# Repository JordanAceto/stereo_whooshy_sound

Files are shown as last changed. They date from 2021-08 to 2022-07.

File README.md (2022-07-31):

# Stereo Whooshy Sound

## This pedal accommodates various VCF plug-in boards and contains rich modulation features.
- The interface is loosely modeled after the Mu-Tron Bi-Phase with some additions.
- Flexible signal path configurations are possible, including true stereo, dual-mono, and series setups.

## [SCHEMATIC](https://github.com/JordanAceto/stereo_whooshy_sound/blob/master/hardware/main_pcb/construction_docs/stereo_whooshy_sound_schematic.pdf)

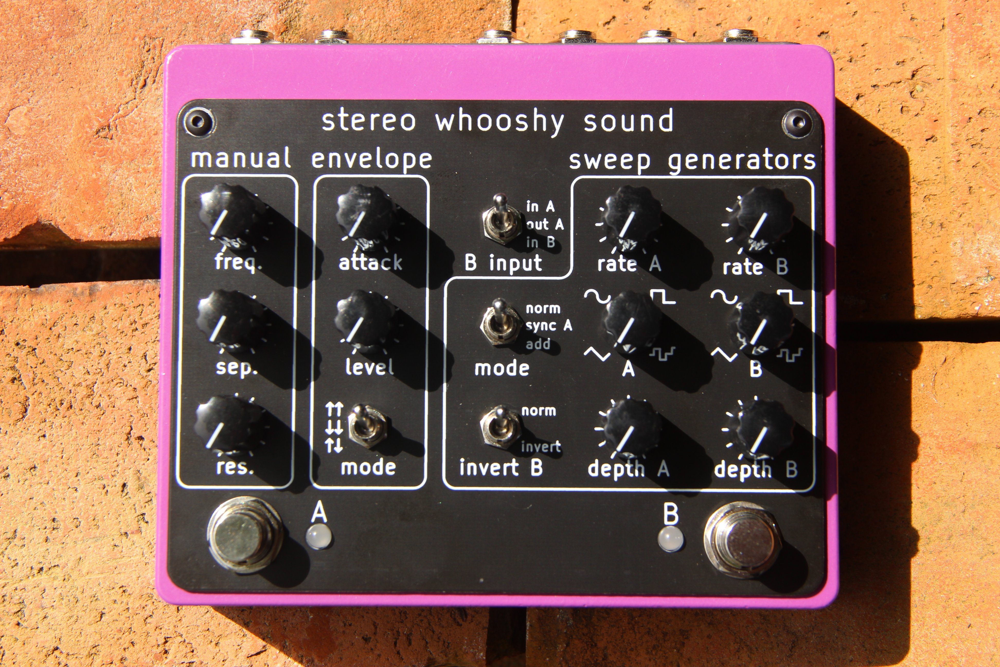
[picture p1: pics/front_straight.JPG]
stereo whooshy sound pedal


### Features:
- Guitar pedal style stomp box.
- Can accept a wide variety of [filter plug-in boards](https://github.com/JordanAceto/VCF_plug_in_boards).
- Manual frequency and resonance controls.
- Dual digitally generated LFO with morphing waveshaper, smoothly crossfades from triangle to sine to square to sample & hold.
- Analog envelope follower for when you want to quack and bwow instead of whoosh.
- CV/expression pedal inputs for each filter.

## Status of the project:

Task | Status |
---------|--------------|
Schematic capture | &#9745;
PCB layout | &#9745;
Test build | &#9745;
Safe to order boards| &#9744;

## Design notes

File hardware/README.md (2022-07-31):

# The hardware for the pedal.

- The [main pcb](https://github.com/JordanAceto/stereo_whooshy_sound/tree/master/hardware/main_pcb) is the heart of the project.

- Once the pedal is built, you need at least two [VCF plug-in boards](https://github.com/JordanAceto/VCF_plug_in_boards) to complete the project.

- Various filter plug-in boards can be swapped in and out to experiment with sounds.

- The front panel and jack panel are simple pcb panels as a cheap way to get an ok looking finished project.

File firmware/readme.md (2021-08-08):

# STM32L031 Low Frequency Oscillator

### Based on the LFO used in the [variable slope filter/phaser](http://jhaible.com/legacy/varislope_filter_phaser/varislope_filter_phaser.html) project by the great Jurgen Haible.

---

### Features:

- Three analog control inputs, all ranging from 0v to +3.3v:
    - Frequency: sets the frequency of the LFO, ranges from quite slow to a few tens of Hertz.
    - Wave shape: smoothly crossfades between triangle, sine, square, and sample & hold waveforms.
    - Level: a simple output level control.

- One crossfaded analog output, in the range 0v to +2v.

---

### Brief overview of the algorithm:
- The three control signals are read by the ADC and stored in a buffer via DMA.
- The frequency control is scaled by using a lookup table as an exponential converter.
- Wave shape and level controls are linear.
- A timer configured as a periodic stopwatch sets the sample rate for the LFO.
- The LFO uses a simple form of [direct digital synthesis](https://www.digikey.com/en/articles/the-basics-of-direct-digital-synthesizers-ddss) as its core.
- The LFO waveforms are independently generated:
    - The triangle wave is derived directly from the phase accumulator.
    - The sine wave uses a lookup table.
    - The square wave is also a simple transformation of the raw phase accumulator.
    - A random sample & hold signal is generated via a [Linear Feedback Shift Register](http://citeseerx.ist.psu.edu/viewdoc/summary?doi=10.1.1.43.3639) and sampled at twice the base LFO frequency (this makes it "feel right").
- A wave scanner then smoothly crossfades between the above shapes, in the above order. This creates a fun and intuitive transition from smooth, to choppy, to chaotic LFO shapes.
- Since the LFO is very low frequency and only used for modulation purposes, no attempts to mitigate aliasing are attempted.
- The final analog output is created by a cheap 12 bit SPI DAC.
- Lookup tables are generated by a python script located in the `utils` directory.

---

### Prerequisites for building and flashing the project:
- [arm-none-eabi toolchain](https://developer.arm.com/tools-and-software/open-source-software/developer-tools/gnu-toolchain/gnu-rm/downloads)
- [GNU make](https://www.gnu.org/software/make/)
- [st-link utility](https://www.st.com/en/development-tools/stsw-link004.html)
- A physical st-link device. I use an old [Nucleo board](https://www.st.com/en/evaluation-tools/stm32-nucleo-boards.html).
- If you have a different preferred method of flashing STM32 chips (openocd, etc) then feel free to go wild.

### To build the project:
- `$ make`

### To flash an STM32 chip connected to an st-link programmer via the SWD header:
- `$ make write`

---

### Firmware directory organization:
- `third_party` contains the STM32 supplied CMSIS header-only files, assembly startup routine, and linker script.
- `BSP` is a very basic "Board Support Package", this module initializes and modifies the various stm32 peripherals used by the system.
- `lib` contains user library files.
- `src` contains the main application files.
- `utils` contains non-c language utility source files such as a python lookup table generating script.
- `bin` is the destination for output files generated by the build process.

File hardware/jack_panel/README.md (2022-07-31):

# jack panel:

## The jack panel is simply a cheap and cheerful pcb panel, as an alternative to dymo labels or silkscreening

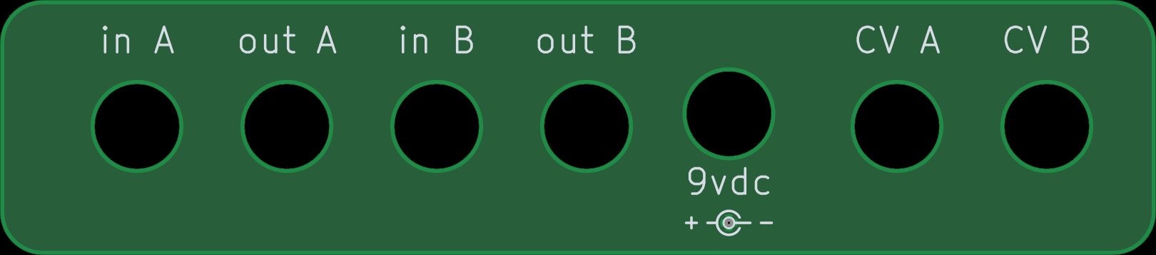
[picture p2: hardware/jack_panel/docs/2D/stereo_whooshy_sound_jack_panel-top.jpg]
jack panel


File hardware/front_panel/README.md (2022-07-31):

# front panel:

## The front panel is simply a cheap and cheerful pcb panel, as an alternative to dymo labels or silkscreening

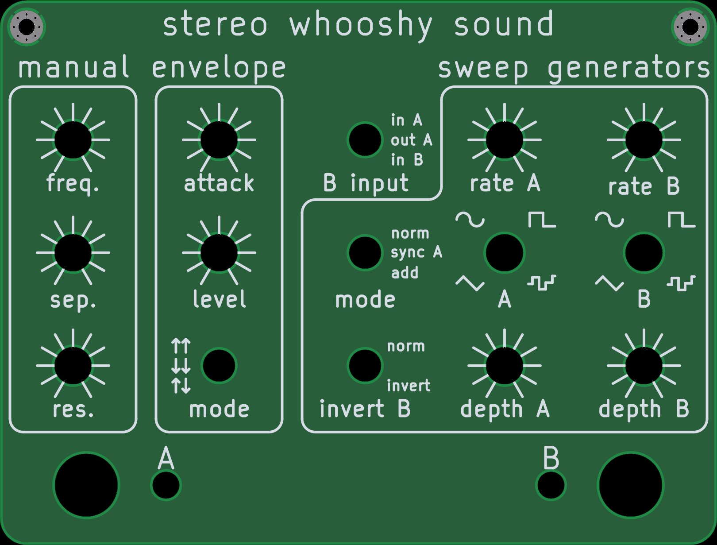
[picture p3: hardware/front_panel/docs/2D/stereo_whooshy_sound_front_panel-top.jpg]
front panel


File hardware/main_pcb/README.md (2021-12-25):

# Main PCB

## The main PCB contains:
- input and output audio buffers
- software generated LFOs
- envelope followers
- two ports which accepts various VCF plug-in boards
- analog bypass switching
- power supply components
- designed to fit in a Hammond 1590XX enclosure

---

## [Schematic](https://github.com/JordanAceto/stereo_whooshy_sound/blob/master/hardware/main_pcb/construction_docs/stereo_whooshy_sound_schematic.pdf)

---

### PCB front view:
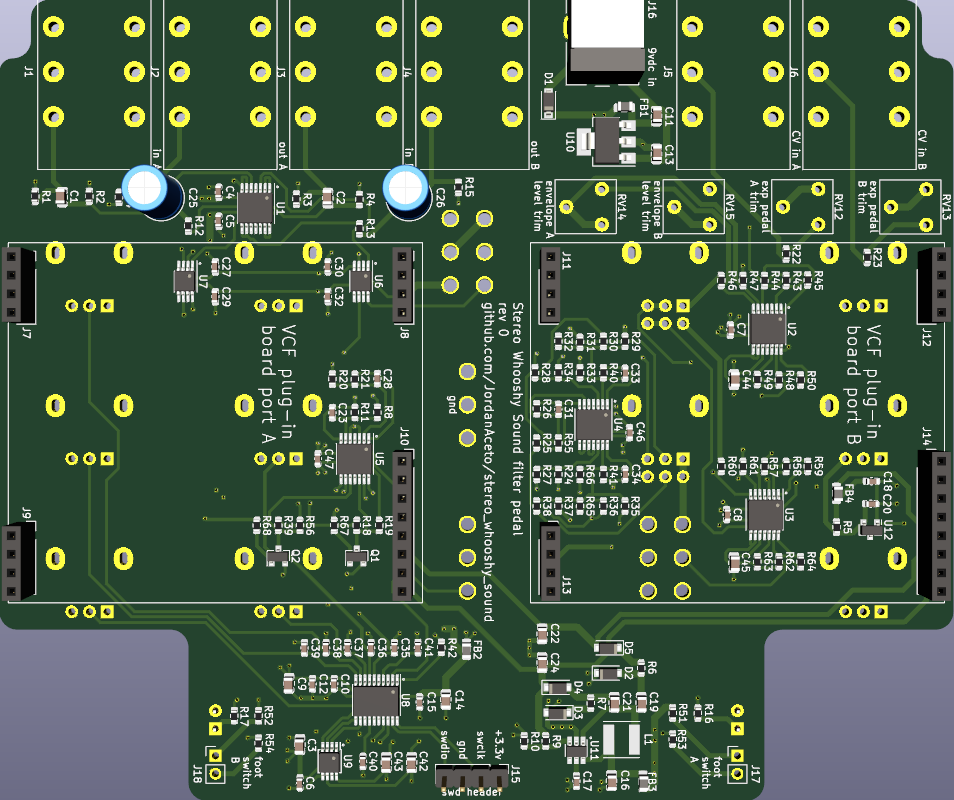
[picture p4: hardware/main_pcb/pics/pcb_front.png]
main PCB front view


---

### PCB rear view:
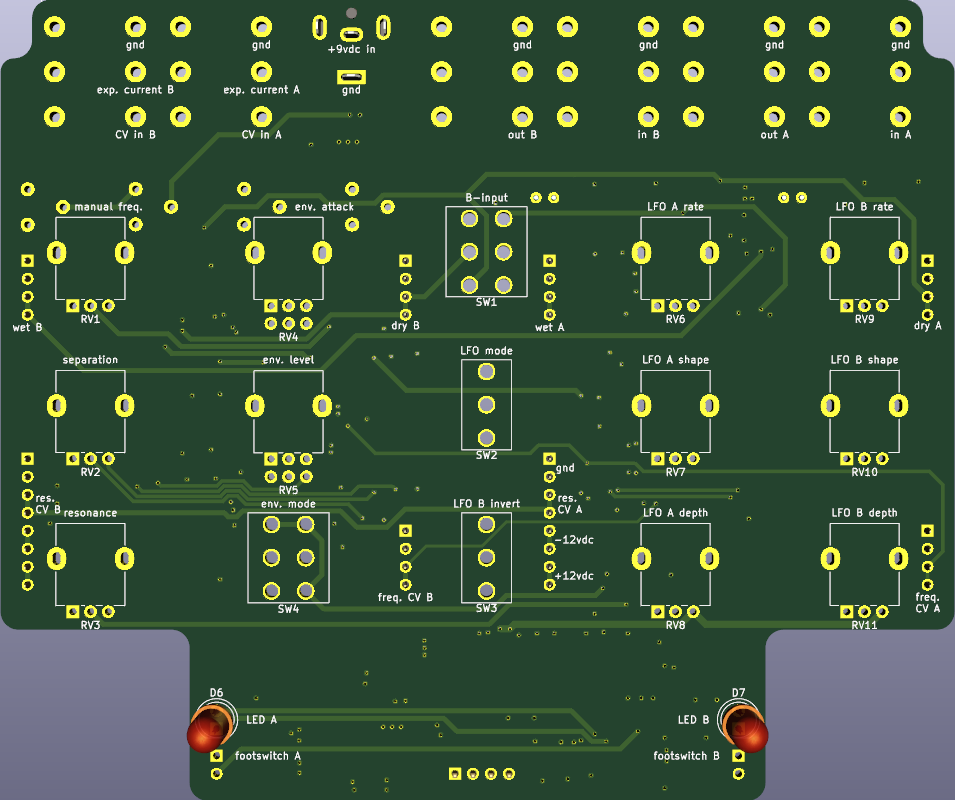
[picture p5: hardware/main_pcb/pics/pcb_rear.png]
main PCB rear view


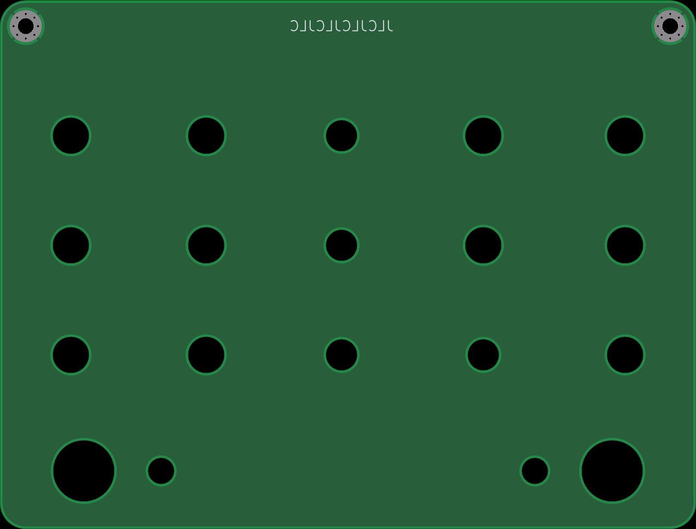
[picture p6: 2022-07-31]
hardware/front_panel/docs/2D/stereo_whooshy_sound_front_panel-bottom.jpg

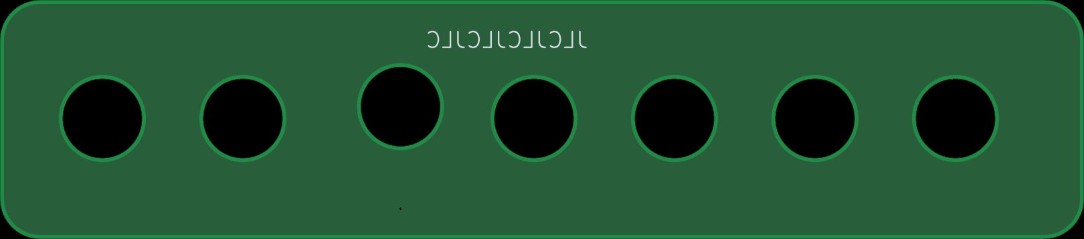
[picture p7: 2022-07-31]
hardware/jack_panel/docs/2D/stereo_whooshy_sound_jack_panel-bottom.jpg

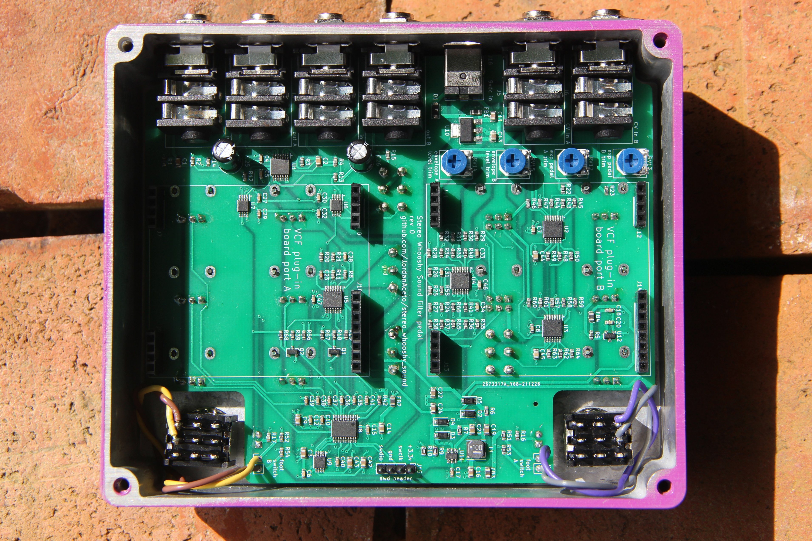
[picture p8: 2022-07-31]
pics/guts_no_plug_in.JPG

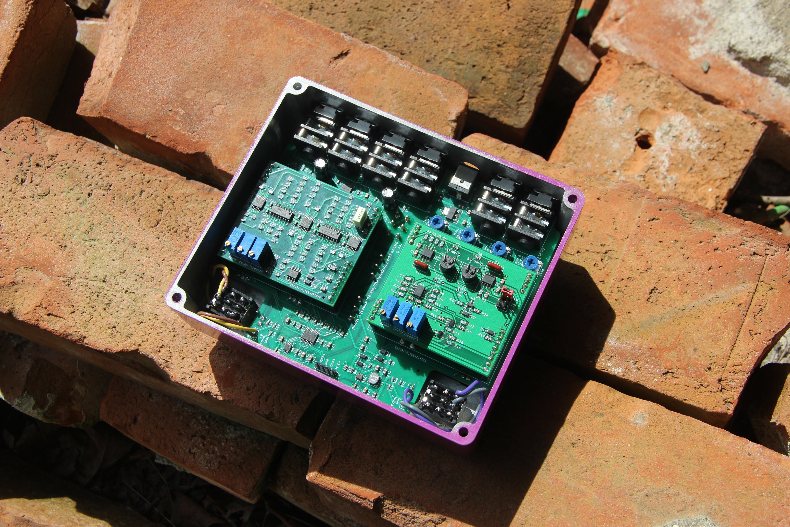
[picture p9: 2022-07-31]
pics/guts_with_plug_in.JPG

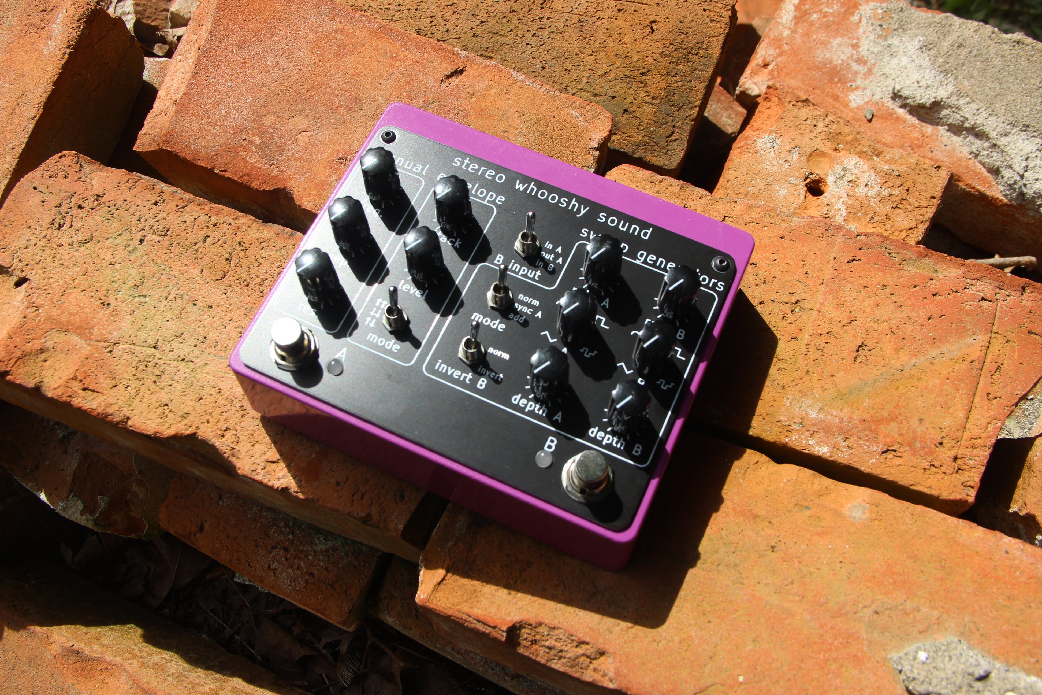
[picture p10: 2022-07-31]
pics/front_angle.JPG

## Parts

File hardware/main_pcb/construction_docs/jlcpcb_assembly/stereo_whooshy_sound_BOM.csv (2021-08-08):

Comment | Designator | Footprint | LCSC Part Number
MMBT3904 | Q1,Q2 | SOT-23-3 | C20526
12k | R19,R56,R27 | 0603 | C22790
120k | R67,R18,R68,R39,R41,R40,R38,R37,R30,R32,R31,R26,R21 | 0603 | C25808
DG469EQ | U7,U6 | MSOP-8_3x3.0x0.65P | C145215
MCP6004 | U5,U4,U3,U2 | TSSOP-14_4.4x5_P0.65P | C50282
TL074 | U1 | TSSOP-14_4.4x5_P0.65P | C96507
300k | R66,R65,R55,R36,R35,R33,R29,R25,R20 | 0603 | C23024
10k | R28,R58,R52,R51,R44,R42,R23,R22,R15,R14 | 0603 | C25804
100k | R24,R64,R63,R62,R50,R49,R48,R34,R8 | 0603 | C25803
1M | R54,R53 | 0603 | C22935
100n | C32,C30,C29,C27,C47,C46,C41,C40,C39,C38,C37,C36,C35,C31,C23,C20,C18,C17,C15,C12,C10,C8,C7,C6,C5,C4 | 0603 | C14663
1k2 | R61,R47,R17,R16,R13,R12 | 0603 | C22765
4k7 | R60,R46 | 0603 | C23162
30k | R59,R45 | 0603 | C22984
20k | R57,R43,R11 | 0603 | C4184
470n | C45,C44 | 0805 | C13967
4n7 | C2,C1 | 0805 | C1744
1R | R7,R6 | 0603 | C22936
2k2 | R5 | 0603 | C4190
2M2 | R4,R3,R2,R1 | 0603 | C22938
100R @ 100MHz | FB4,FB3,FB2,FB1 | L_0805_2012Metric | C1015
B5819W | D1 | D_SOD-123 | C8598
1u | C43,C42,C21,C19,C14 | 0805 | C28323
22n | C34,C33,C28 | 0603 | C21122
4u7 | C24,C22,C16 | 0805 | C1779
10u | C13,C11,C9,C3 | 0805 | C15850

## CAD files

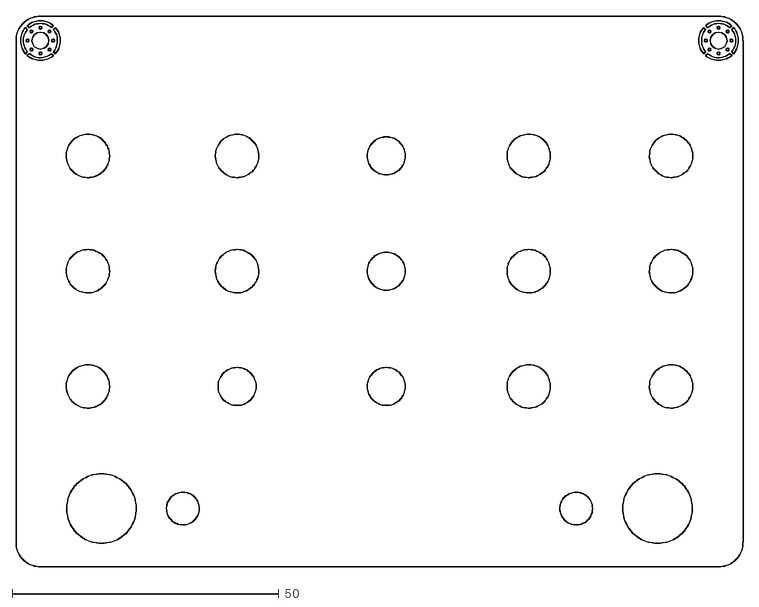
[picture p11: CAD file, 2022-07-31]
hardware/front_panel/docs/CAD/stereo_whooshy_sound_front_panel-B_Cu.dxf
136.1 x 103.1

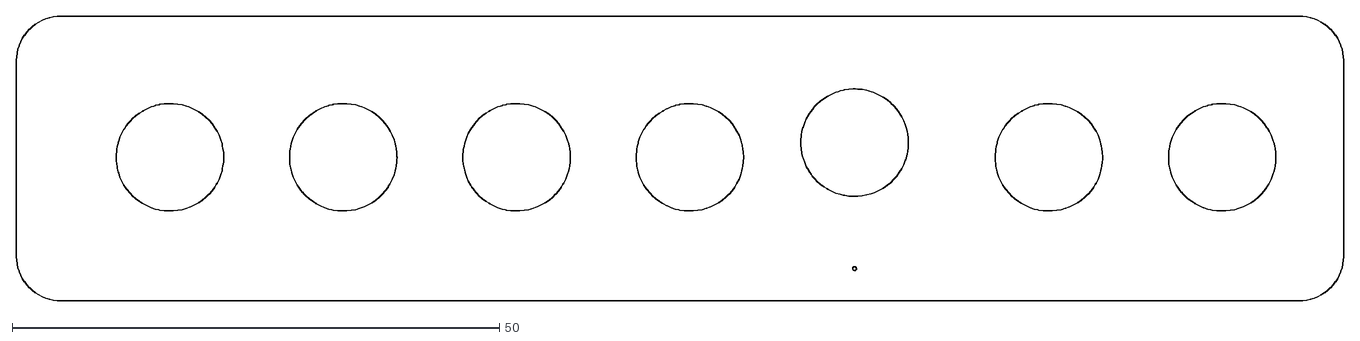
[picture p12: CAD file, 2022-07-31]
hardware/jack_panel/docs/CAD/stereo_whooshy_sound_jack_panel-B_Cu.dxf
136.1 x 29.2

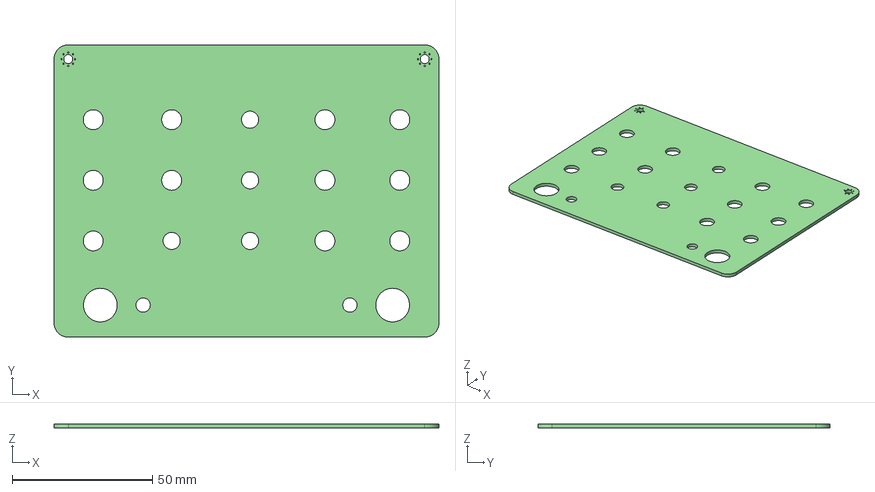
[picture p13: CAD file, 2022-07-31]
hardware/front_panel/docs/CAD/stereo_whooshy_sound_front_panel-3D.step
137.2 x 104.1 x 1.60 mm

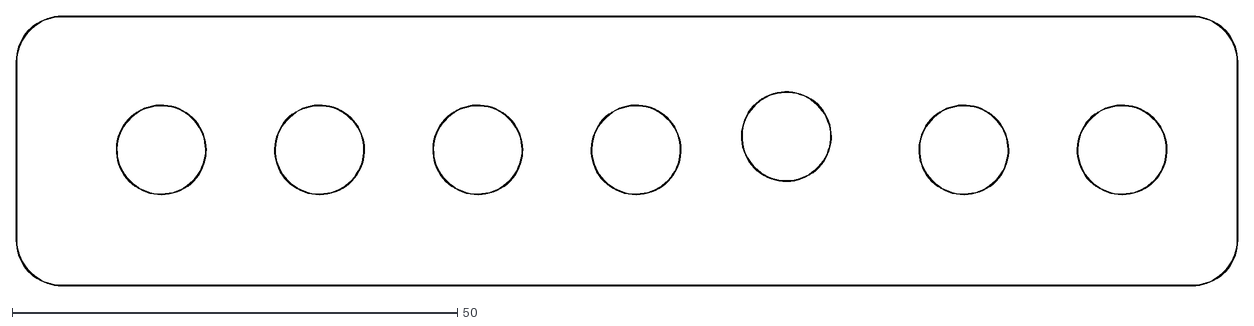
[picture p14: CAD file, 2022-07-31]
hardware/jack_panel/docs/CAD/stereo_whooshy_sound_jack_panel-Edge_Cuts.dxf
137.2 x 30.3

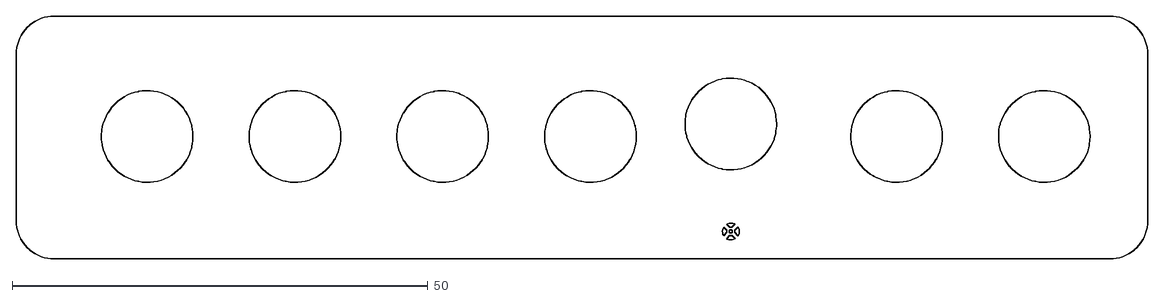
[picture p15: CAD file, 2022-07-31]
hardware/jack_panel/docs/CAD/stereo_whooshy_sound_jack_panel-F_Cu.dxf
136.1 x 29.2

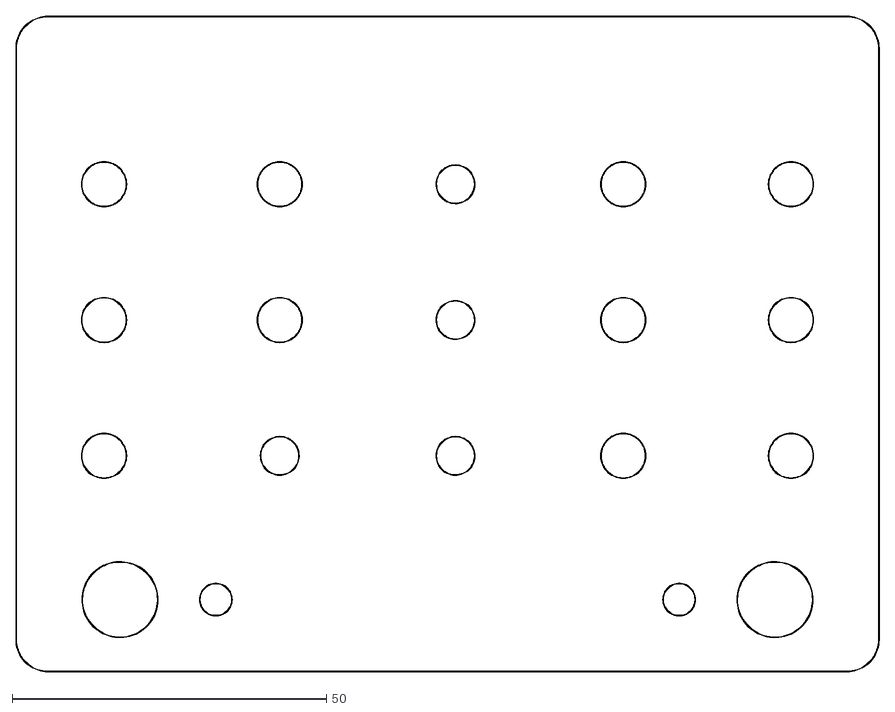
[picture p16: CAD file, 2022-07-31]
hardware/front_panel/docs/CAD/stereo_whooshy_sound_front_panel-Edge_Cuts.dxf
137.2 x 104.2

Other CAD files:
hardware/front_panel/docs/CAD/stereo_whooshy_sound_front_panel-B_Mask.dxf
hardware/front_panel/docs/CAD/stereo_whooshy_sound_front_panel-B_Silkscreen.dxf
hardware/front_panel/docs/CAD/stereo_whooshy_sound_front_panel-F_Mask.dxf
hardware/front_panel/docs/CAD/stereo_whooshy_sound_front_panel-F_Silkscreen.dxf
hardware/jack_panel/docs/CAD/stereo_whooshy_sound_jack_panel-B_Mask.dxf
hardware/jack_panel/docs/CAD/stereo_whooshy_sound_jack_panel-B_Silkscreen.dxf
hardware/jack_panel/docs/CAD/stereo_whooshy_sound_jack_panel-F_Mask.dxf
hardware/jack_panel/docs/CAD/stereo_whooshy_sound_jack_panel-F_Silkscreen.dxf

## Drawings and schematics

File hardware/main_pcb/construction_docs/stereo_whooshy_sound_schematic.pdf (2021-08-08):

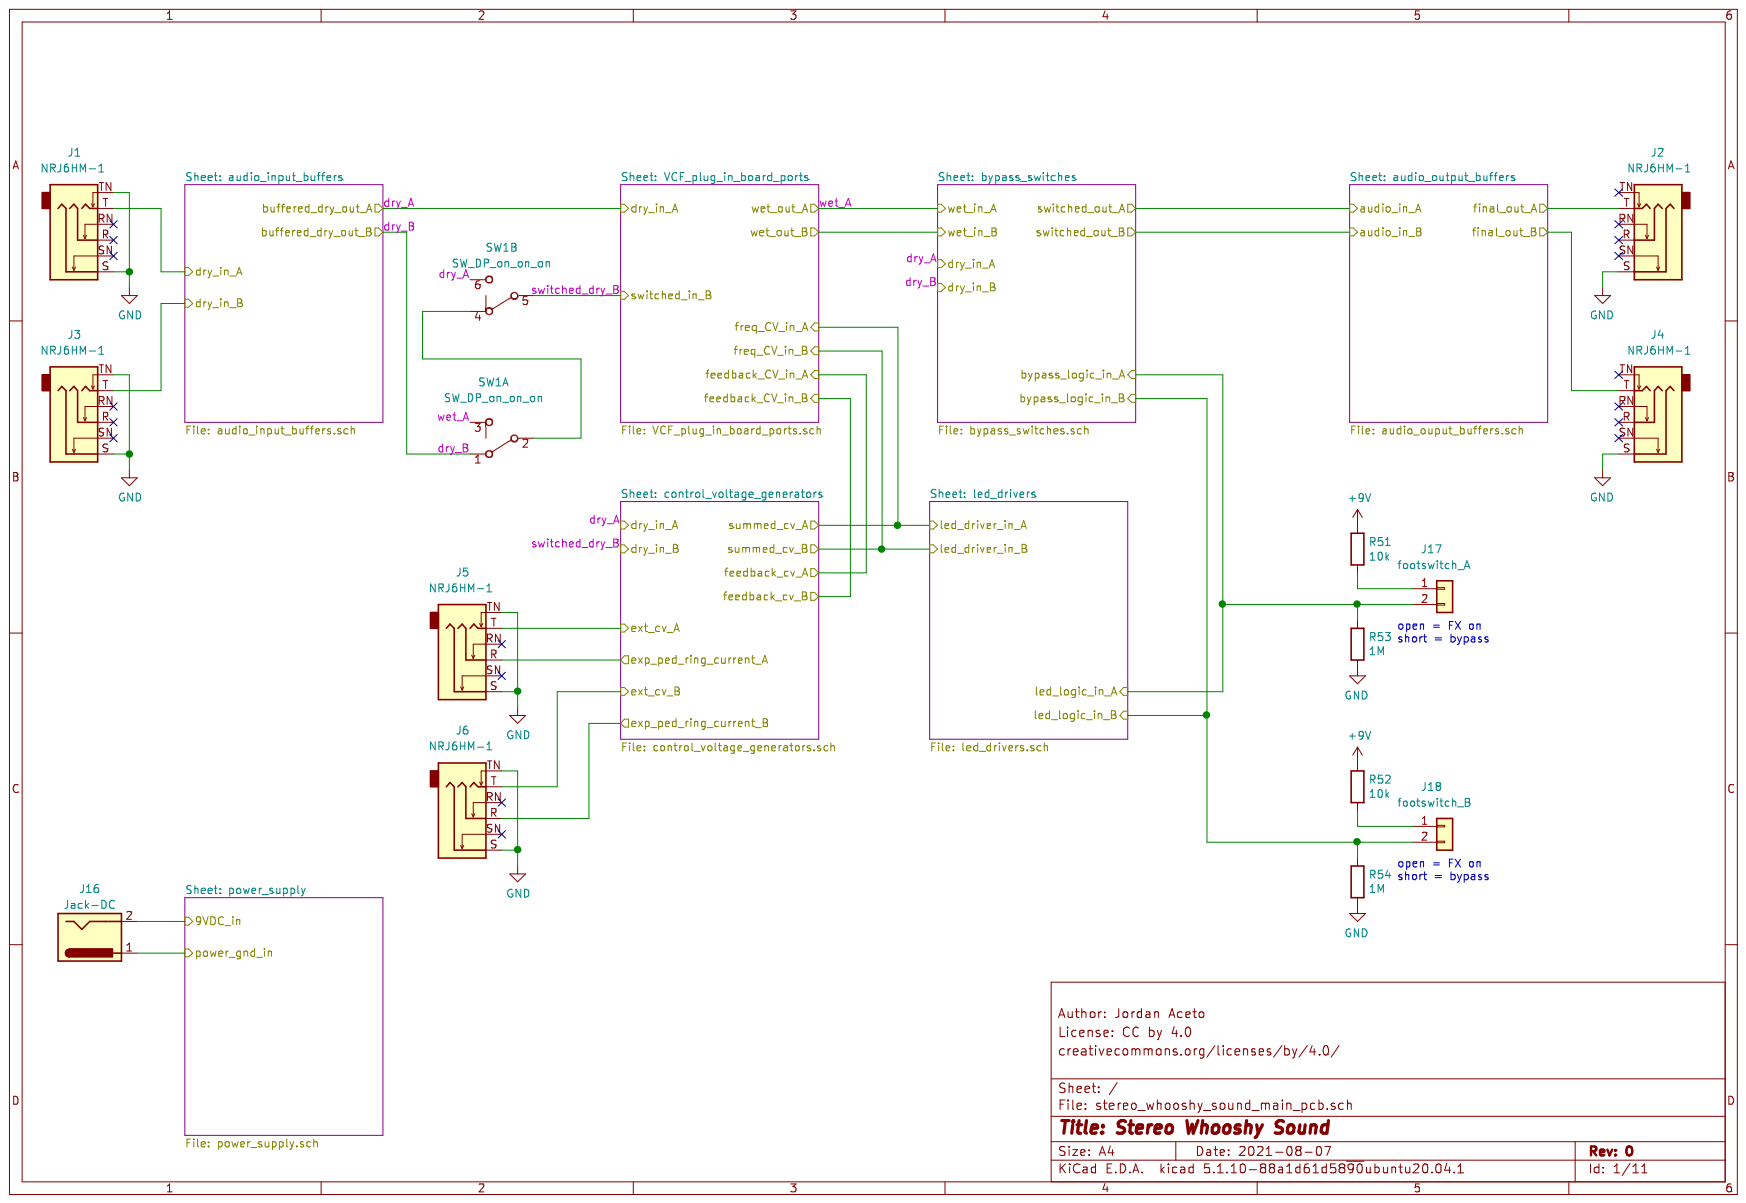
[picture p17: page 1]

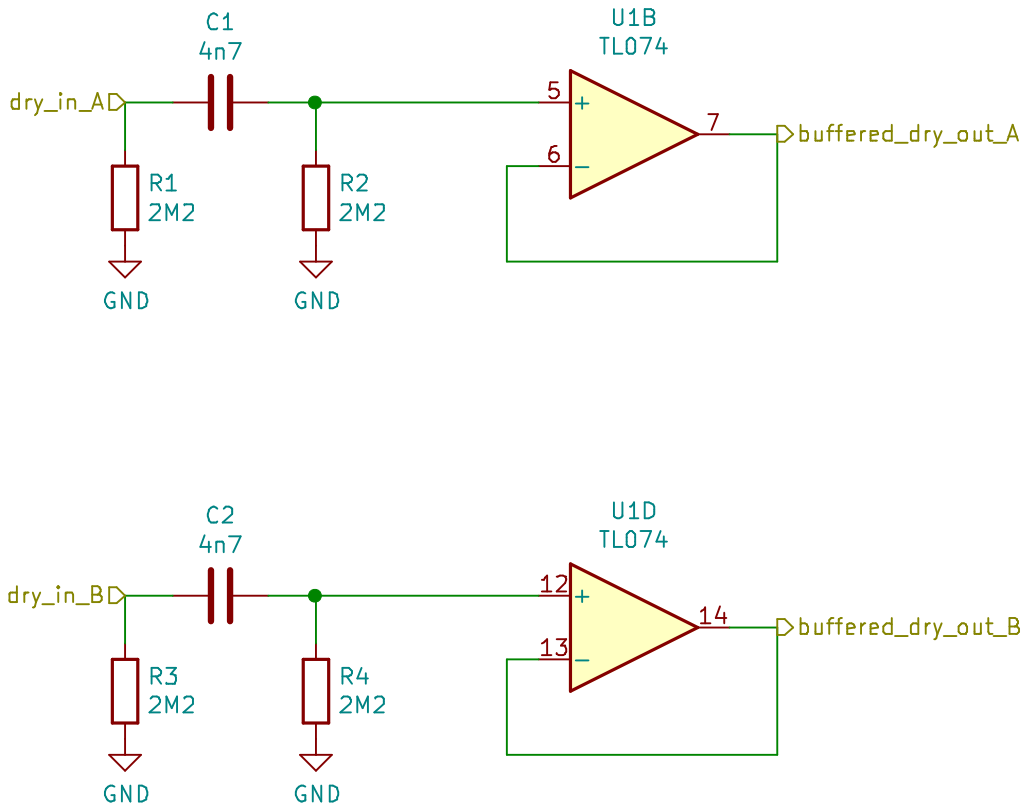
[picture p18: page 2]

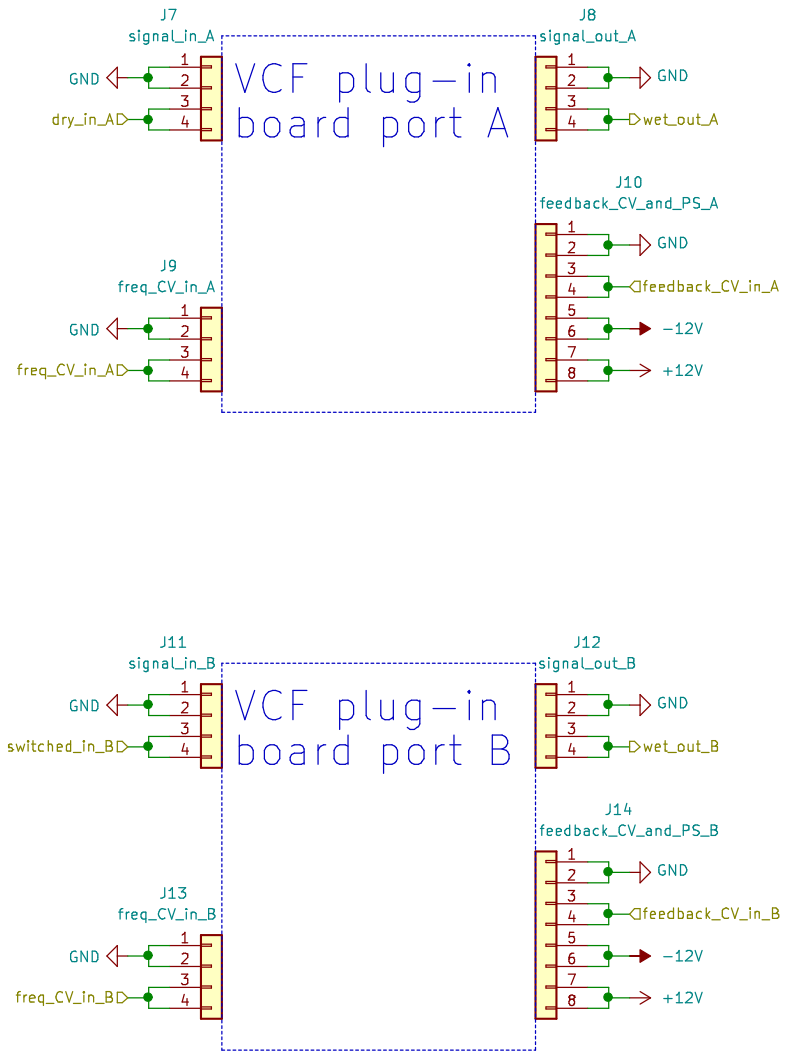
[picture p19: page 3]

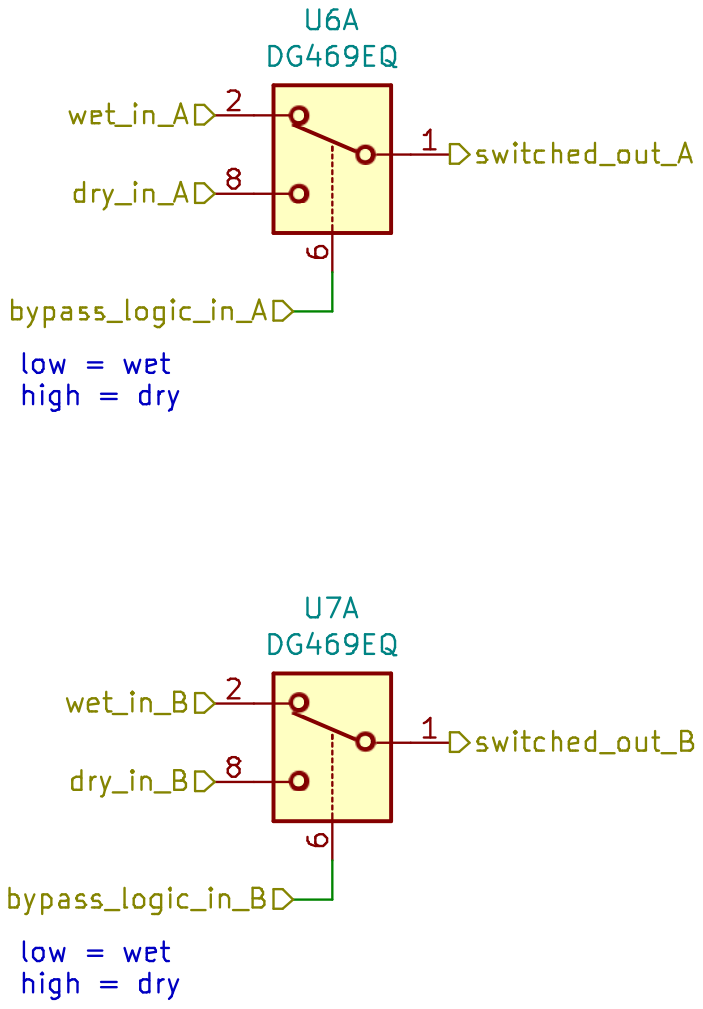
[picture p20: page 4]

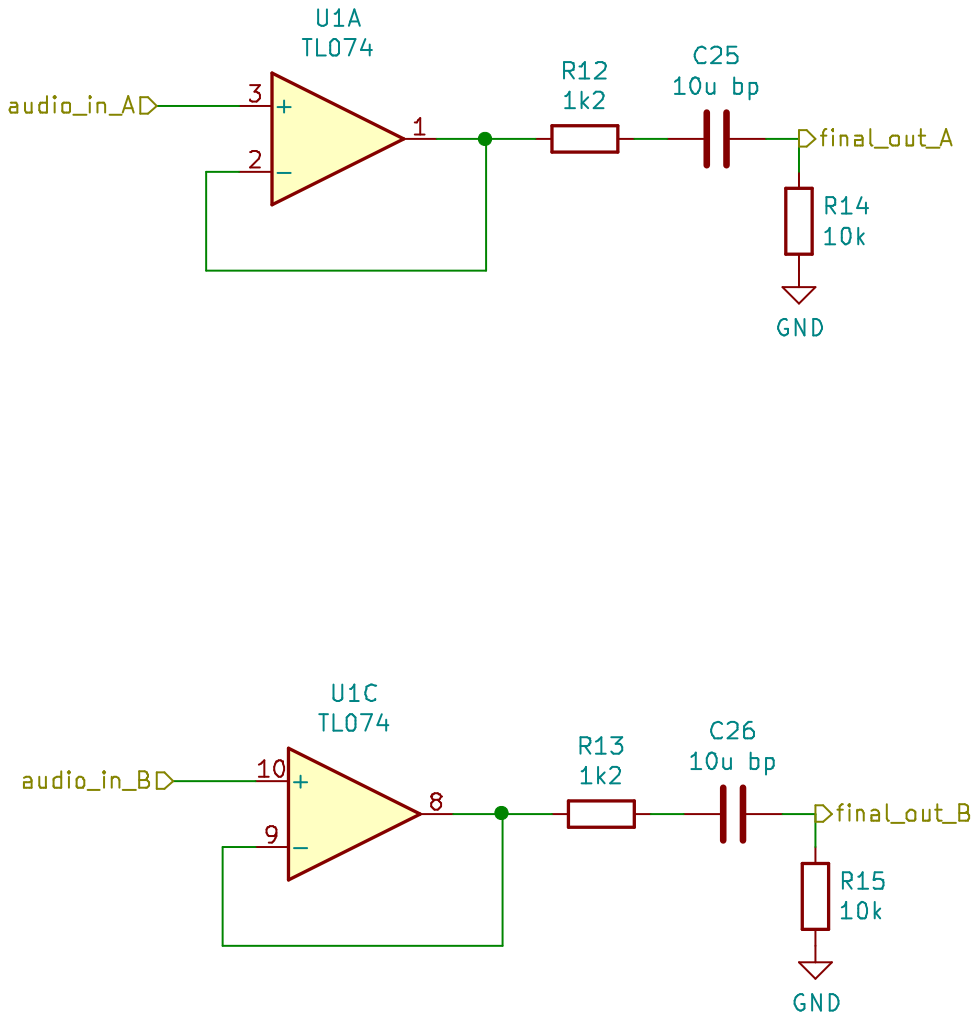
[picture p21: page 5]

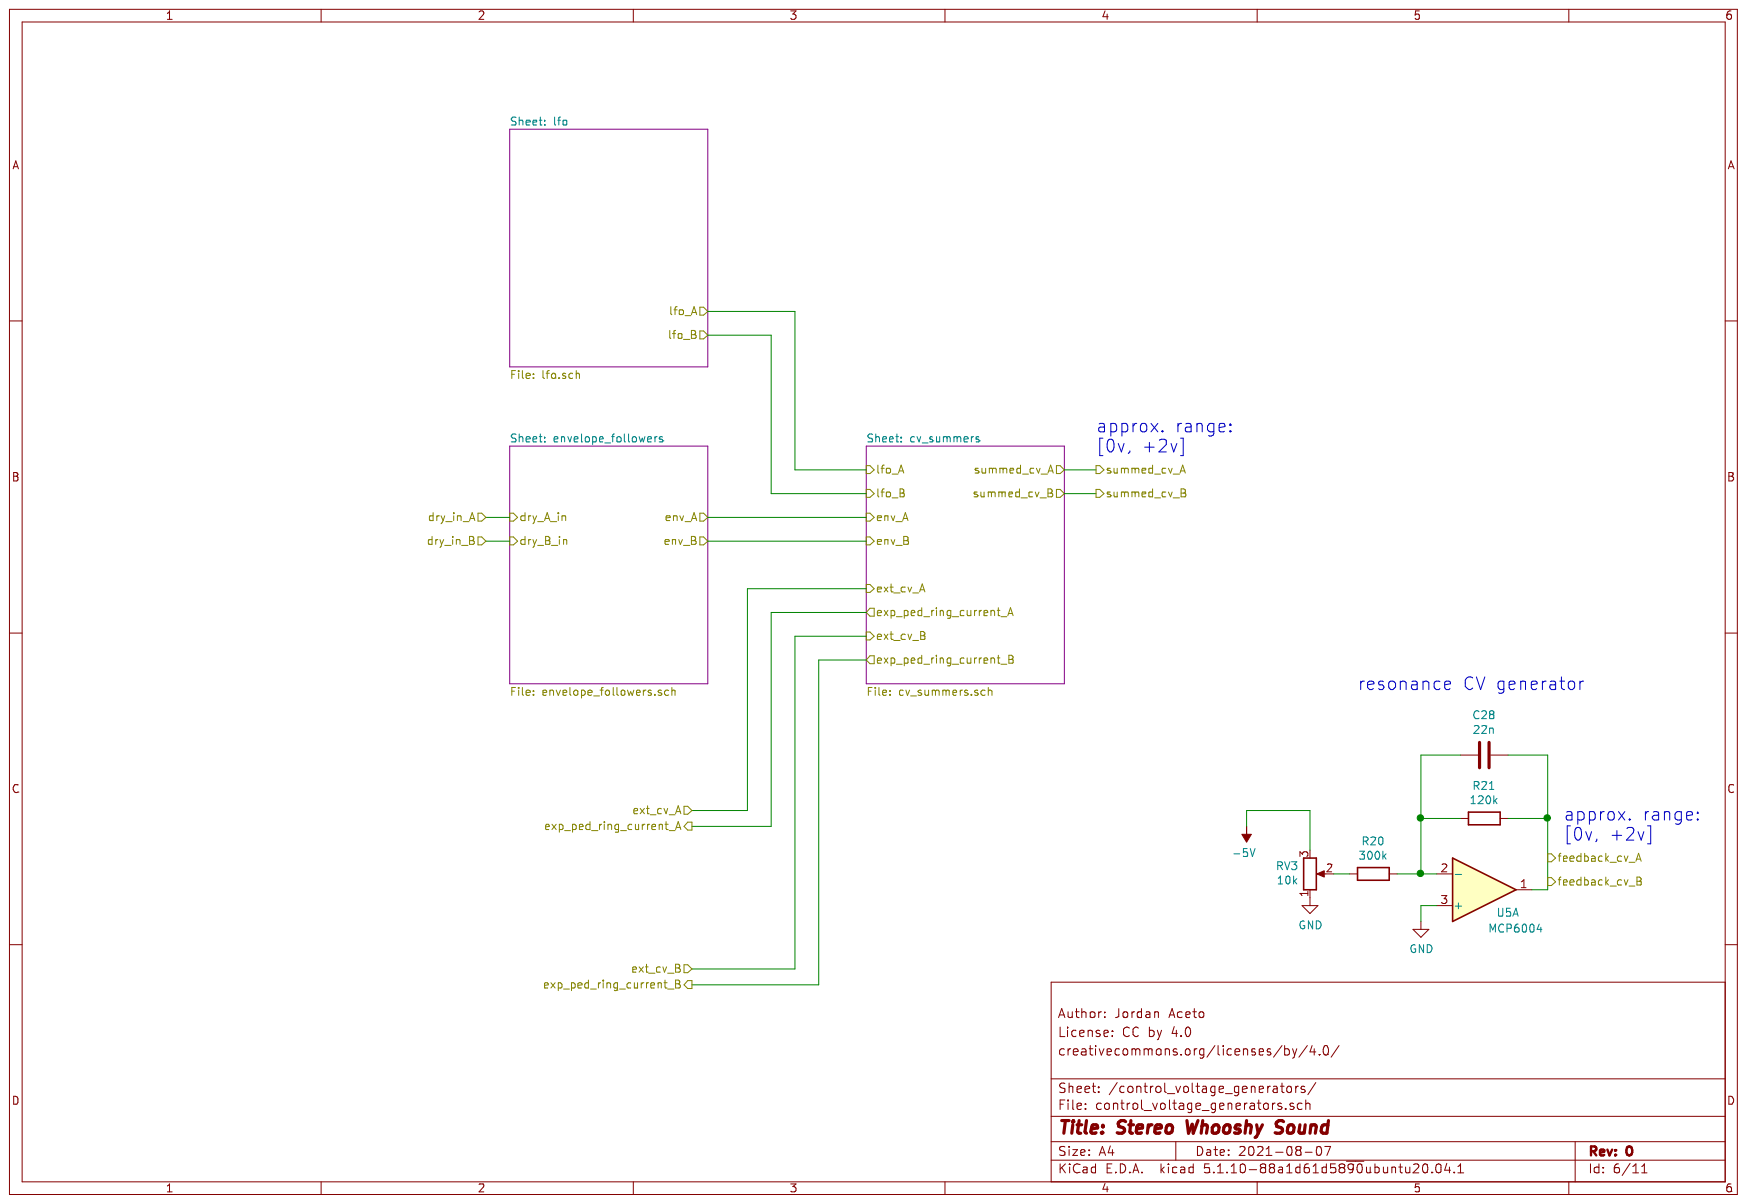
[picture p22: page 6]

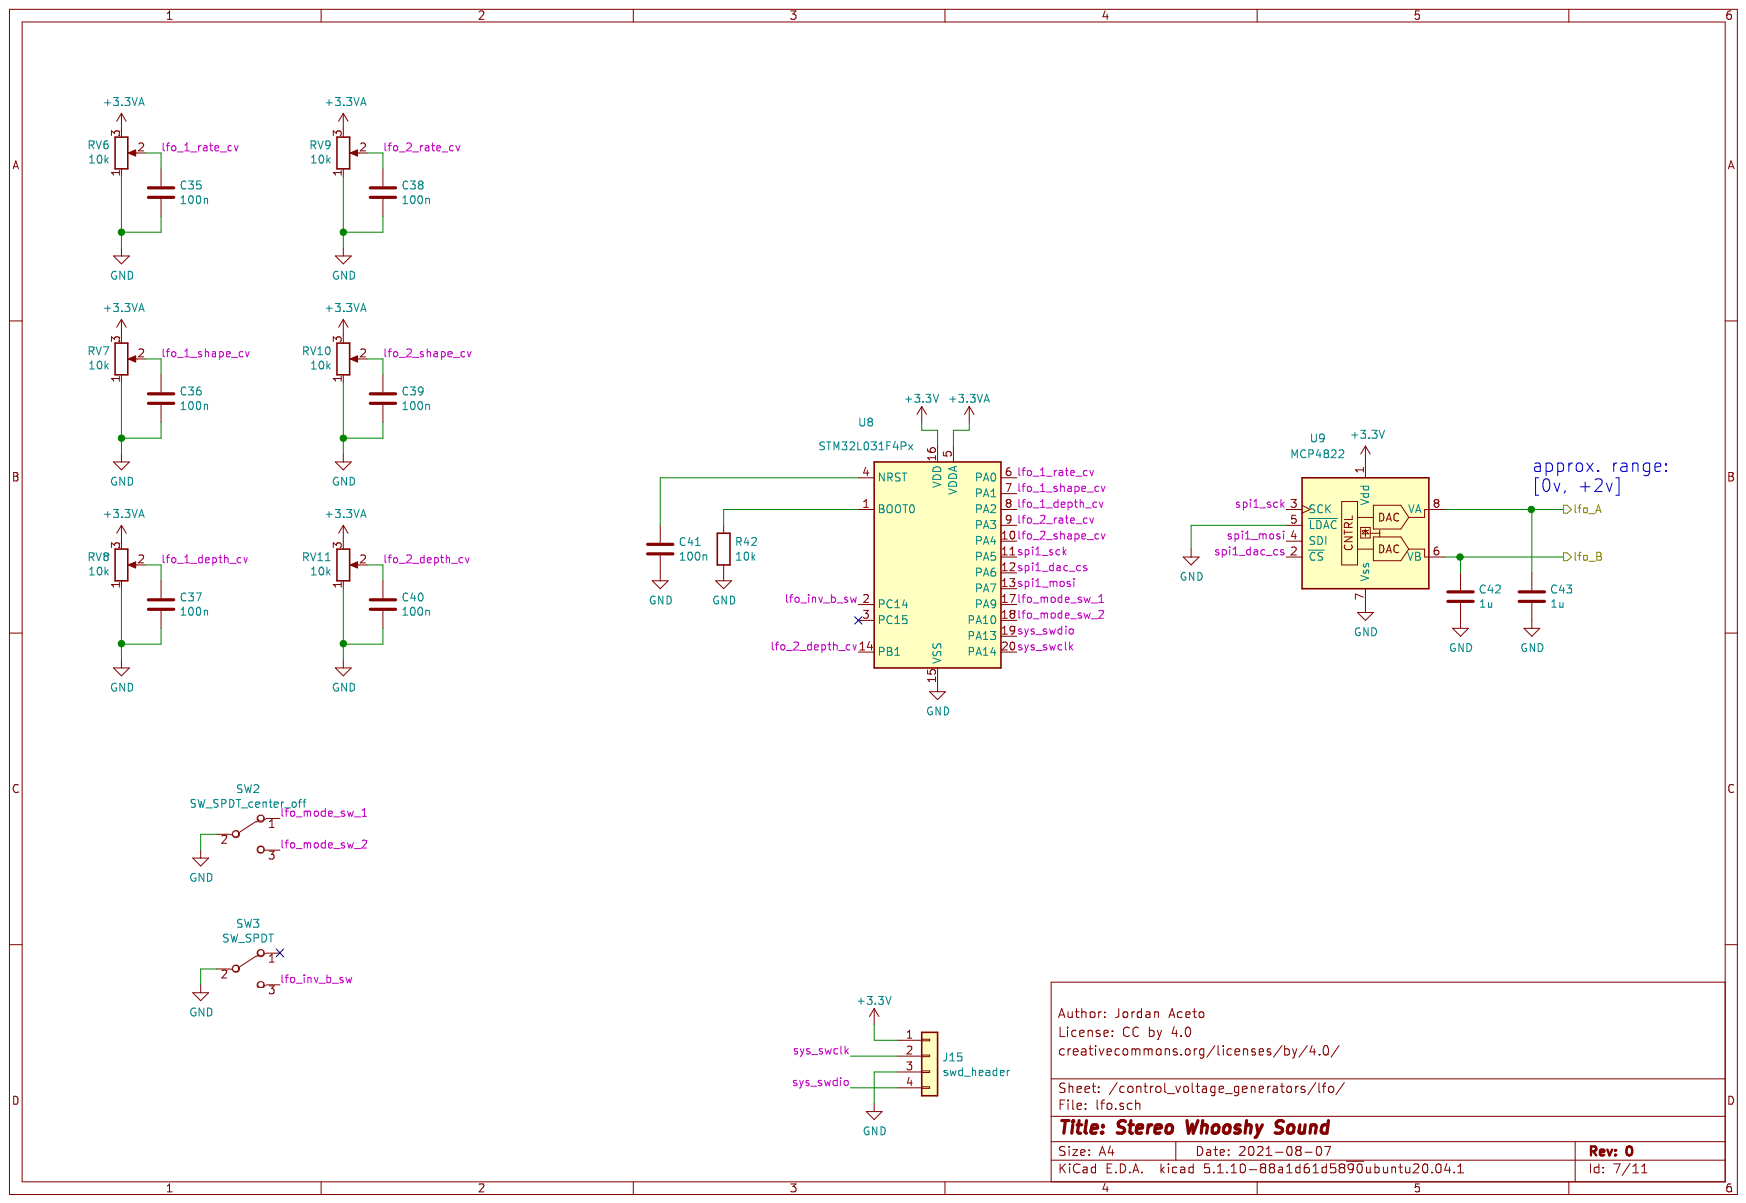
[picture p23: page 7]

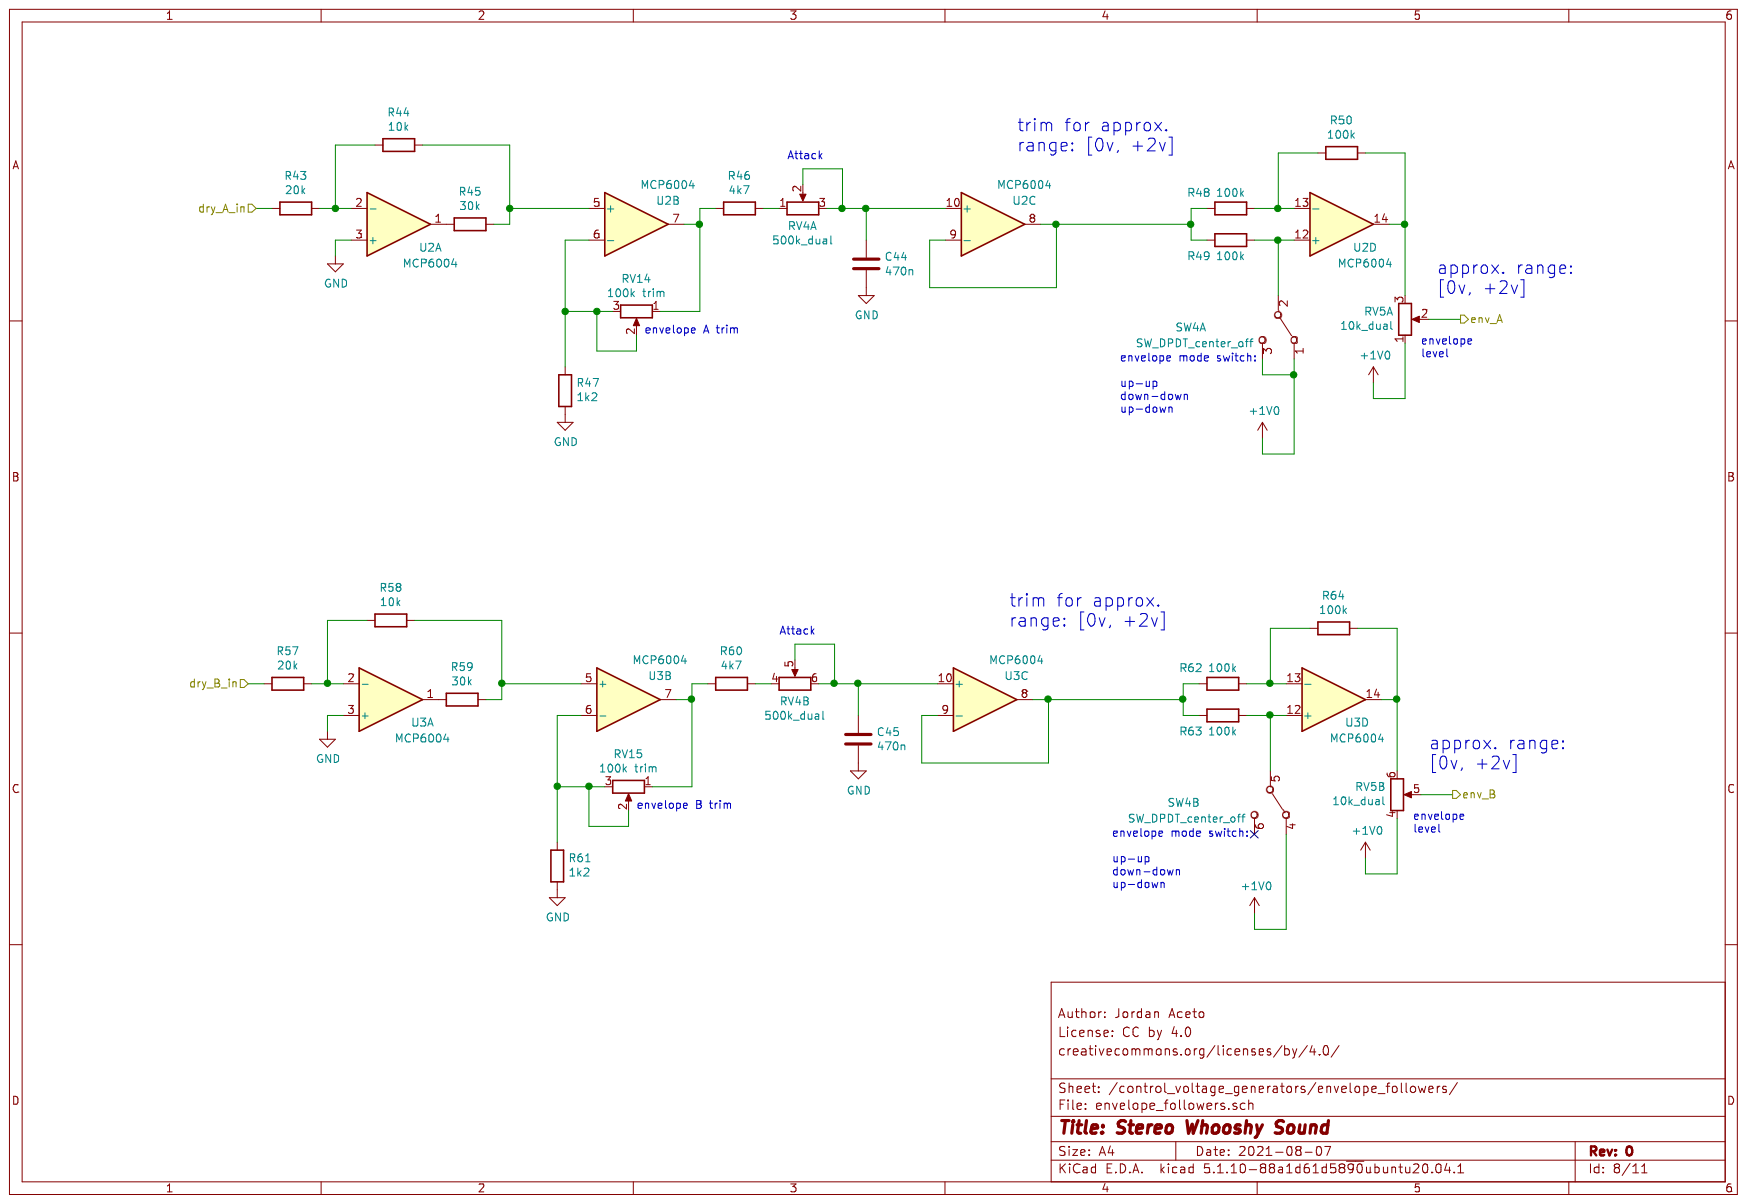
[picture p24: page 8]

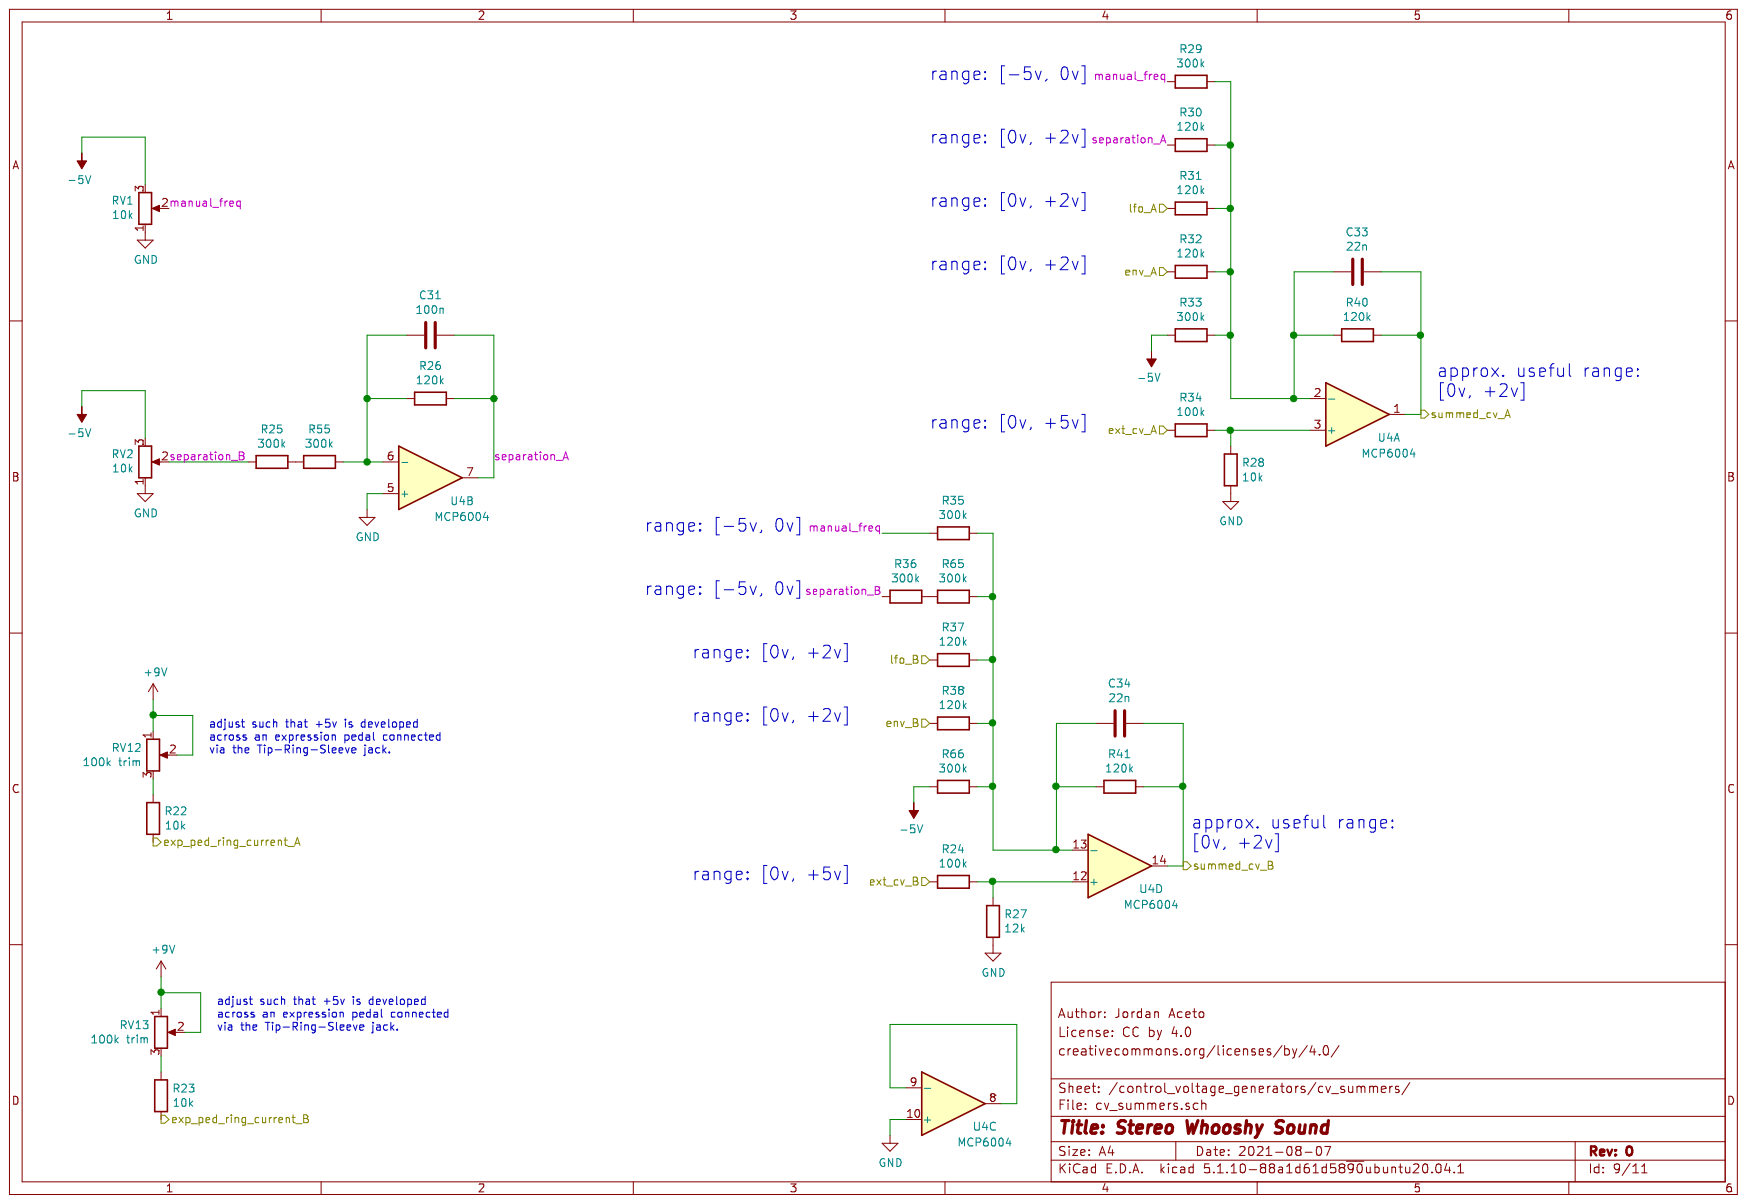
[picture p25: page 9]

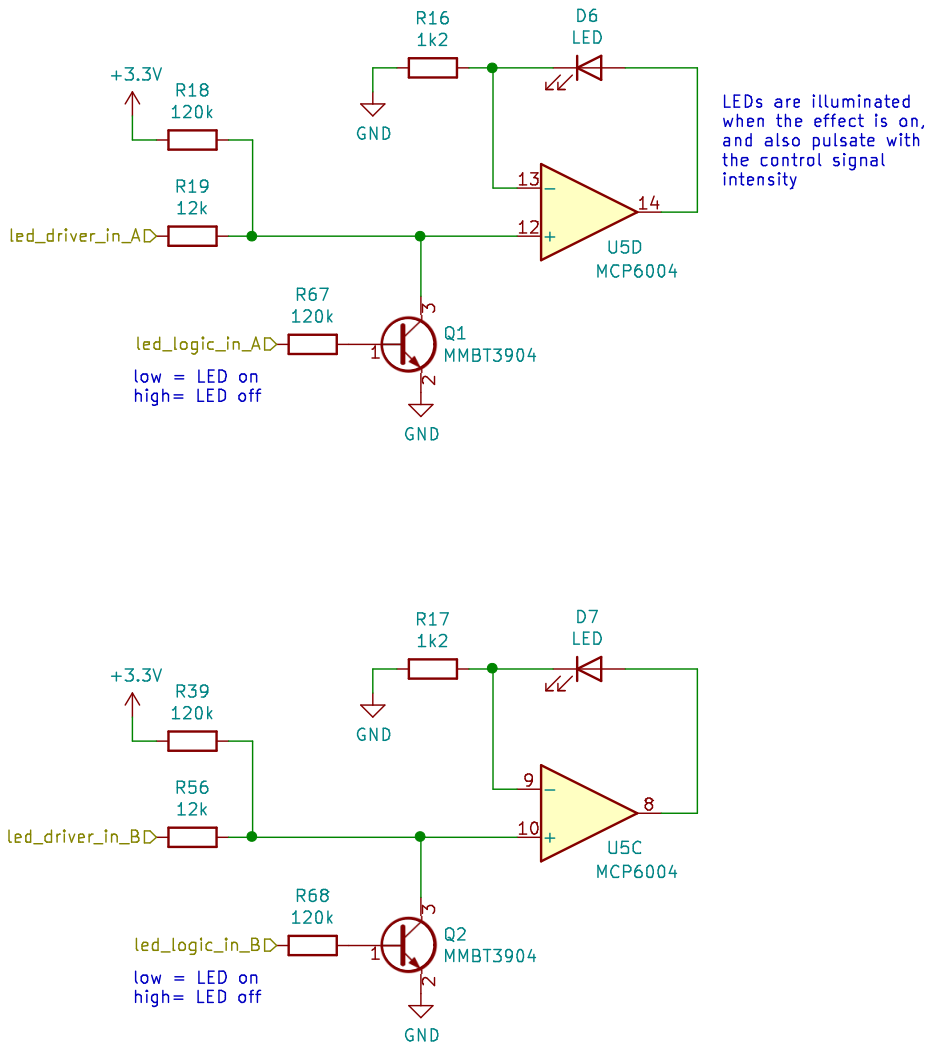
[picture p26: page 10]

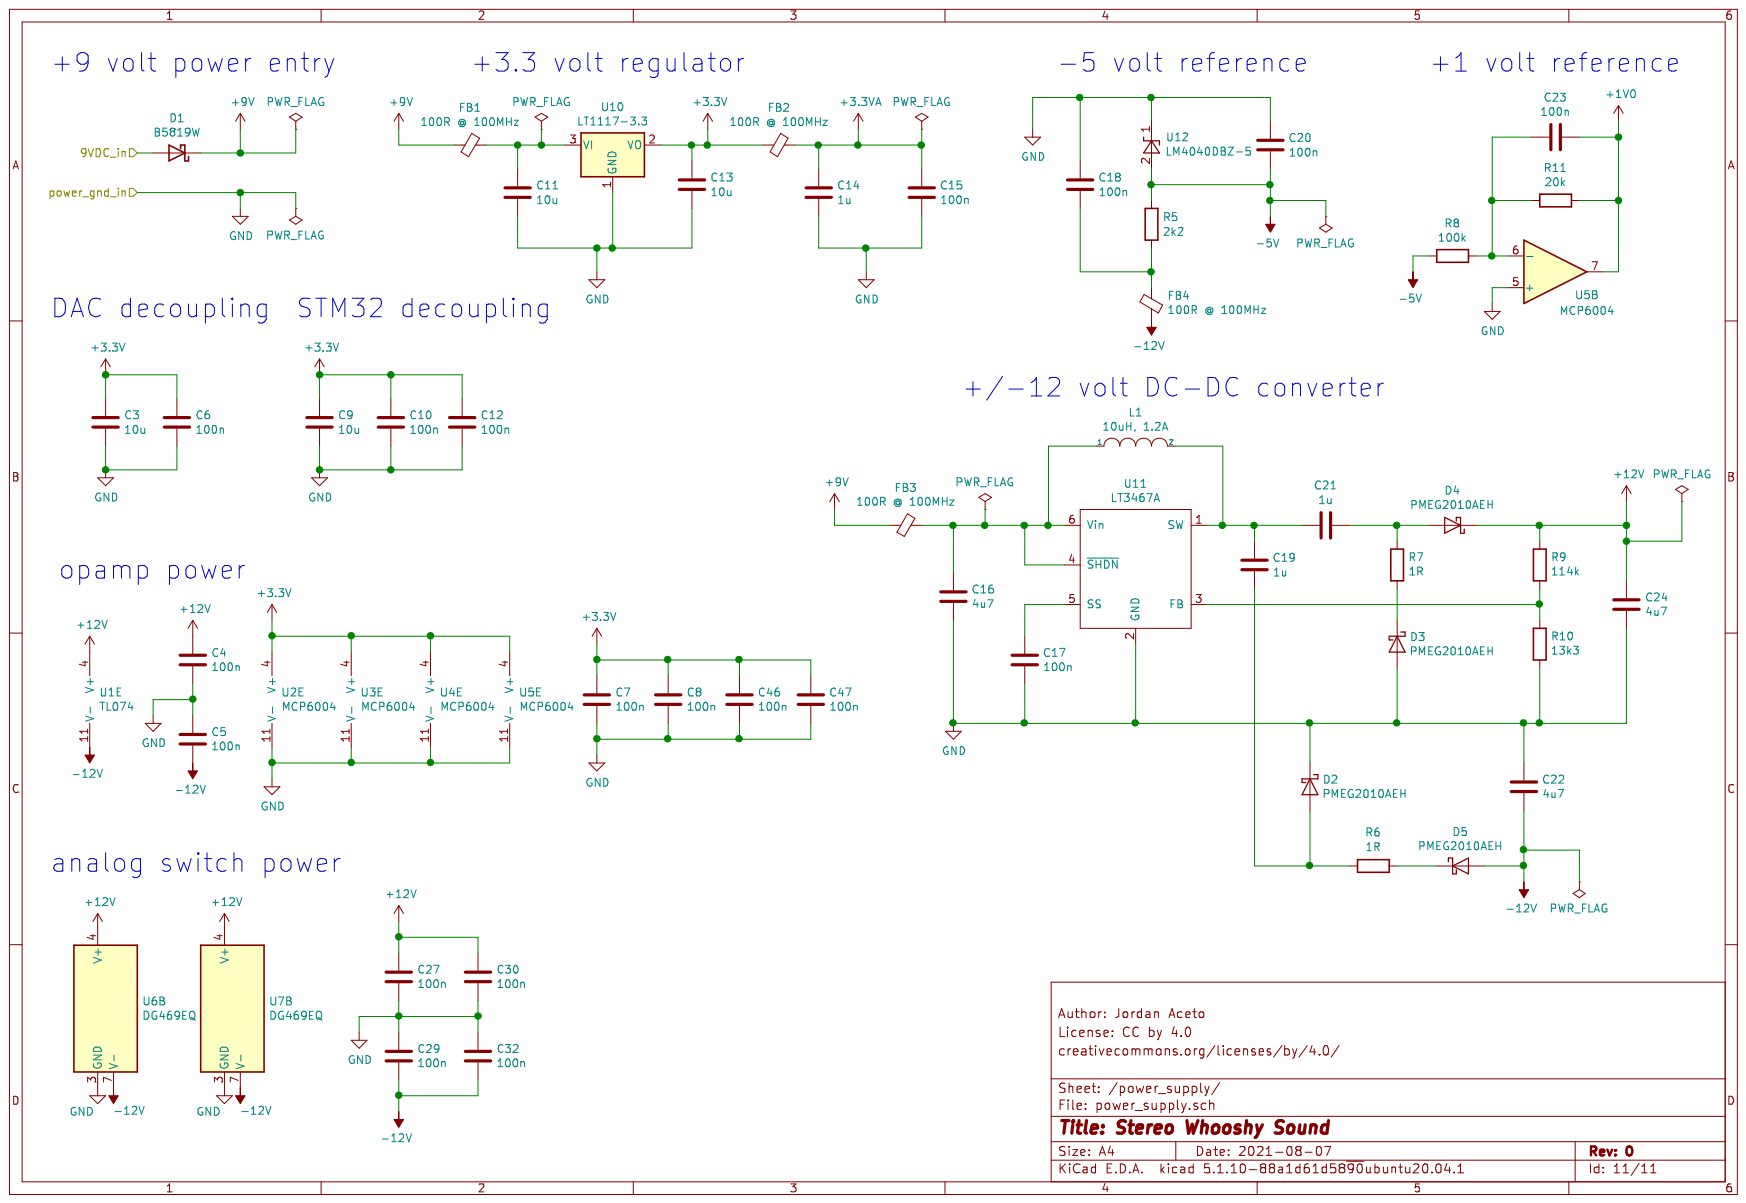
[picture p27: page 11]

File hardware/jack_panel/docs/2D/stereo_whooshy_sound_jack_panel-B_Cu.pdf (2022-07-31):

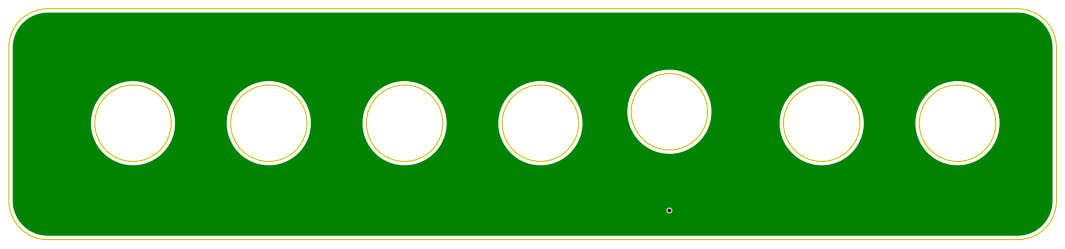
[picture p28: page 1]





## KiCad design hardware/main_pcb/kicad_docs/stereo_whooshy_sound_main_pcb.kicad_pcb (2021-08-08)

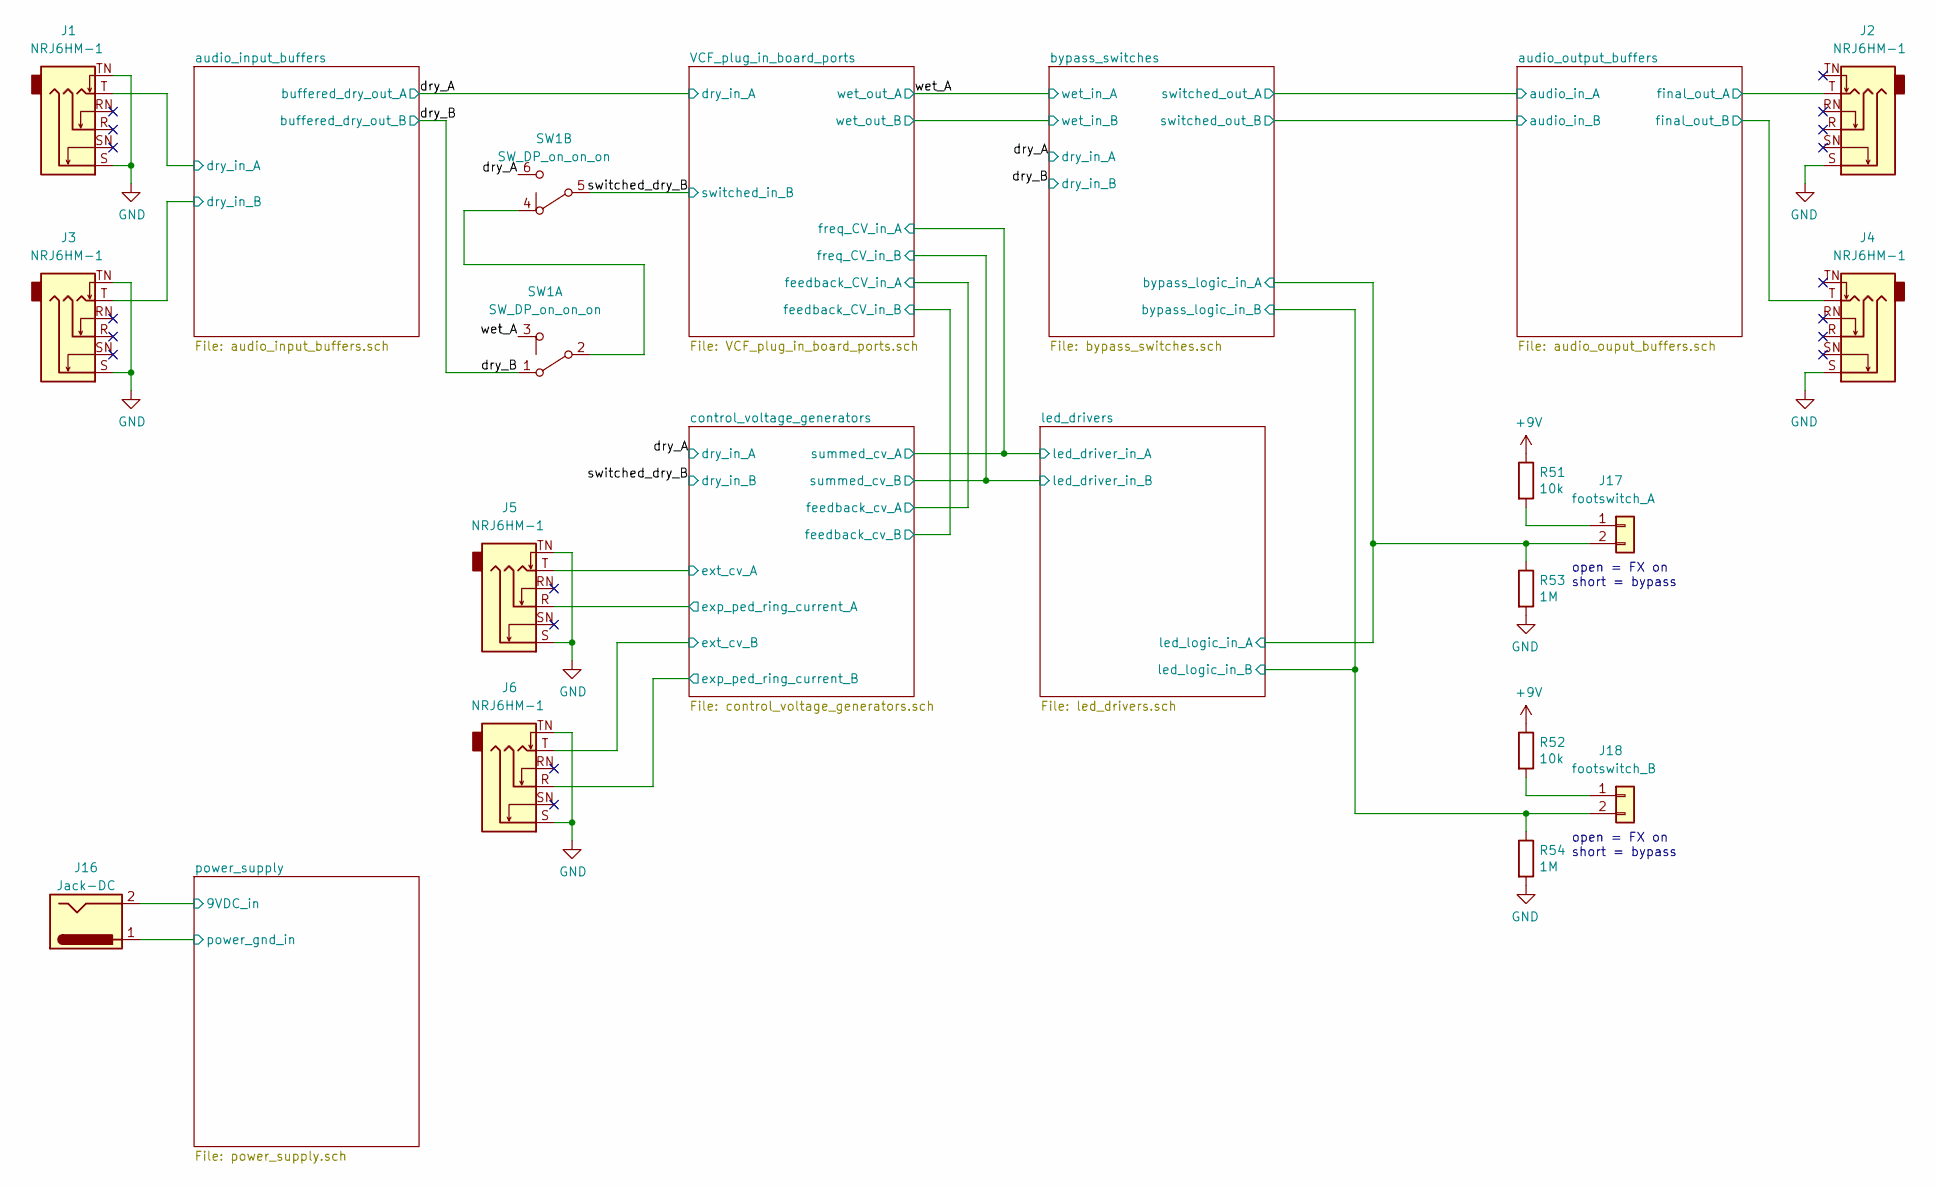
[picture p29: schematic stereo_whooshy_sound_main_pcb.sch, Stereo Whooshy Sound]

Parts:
J1, J2, J3, J4, J5, J6: NRJ6HM-1; Jack_6.35mm_Neutrik_NRJ6HM-1_Horizontal
J16: Jack-DC; BarrelJack_CUI_PJ-063AH_Horizontal
J17: footswitch_A; PinHeader_1x02_P2.54mm_Vertical
J18: footswitch_B; PinHeader_1x02_P2.54mm_Vertical
R51, R52: 10k; R_0603_1608Metric
R53, R54: 1M; R_0603_1608Metric
SW1: SW_DP_on_on_on; DPDT_mini_toggle

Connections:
+9V: R51.1, R52.1; also elsewhere on the board
/audio_input_buffers/dry_in_A: J1.T; also elsewhere on the board
/audio_input_buffers/dry_in_B: J3.T; also elsewhere on the board
/audio_output_buffers/final_out_A: J2.T; also elsewhere on the board
/audio_output_buffers/final_out_B: J4.T; also elsewhere on the board
/bypass_switches/bypass_logic_in_A: J17.2, R53.1; also elsewhere on the board
/bypass_switches/bypass_logic_in_B: J18.2, R54.1; also elsewhere on the board
/control_voltage_generators/exp_ped_ring_current_A: J5.R; also elsewhere on the board
/control_voltage_generators/exp_ped_ring_current_B: J6.R; also elsewhere on the board
/control_voltage_generators/ext_cv_A: J5.T; also elsewhere on the board
/control_voltage_generators/ext_cv_B: J6.T; also elsewhere on the board
/dry_A: SW1.6 (C); also elsewhere on the board
/dry_B: SW1.1 (A); also elsewhere on the board
/power_supply/9VDC_in: J16.2; also elsewhere on the board
/switched_dry_B: SW1.5 (B); also elsewhere on the board
/wet_A: SW1.3 (C); also elsewhere on the board
GND: J1.S, J1.TN, J2.S, J3.S, J3.TN, J4.S, J5.S, J5.TN, J6.S, J6.TN, J16.1, R53.2, R54.2; also elsewhere on the board
unnamed: J17.1, R51.2
unnamed: J18.1, R52.2
unnamed: SW1.2 (B), SW1.4 (A)

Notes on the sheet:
open = FX on short = bypass

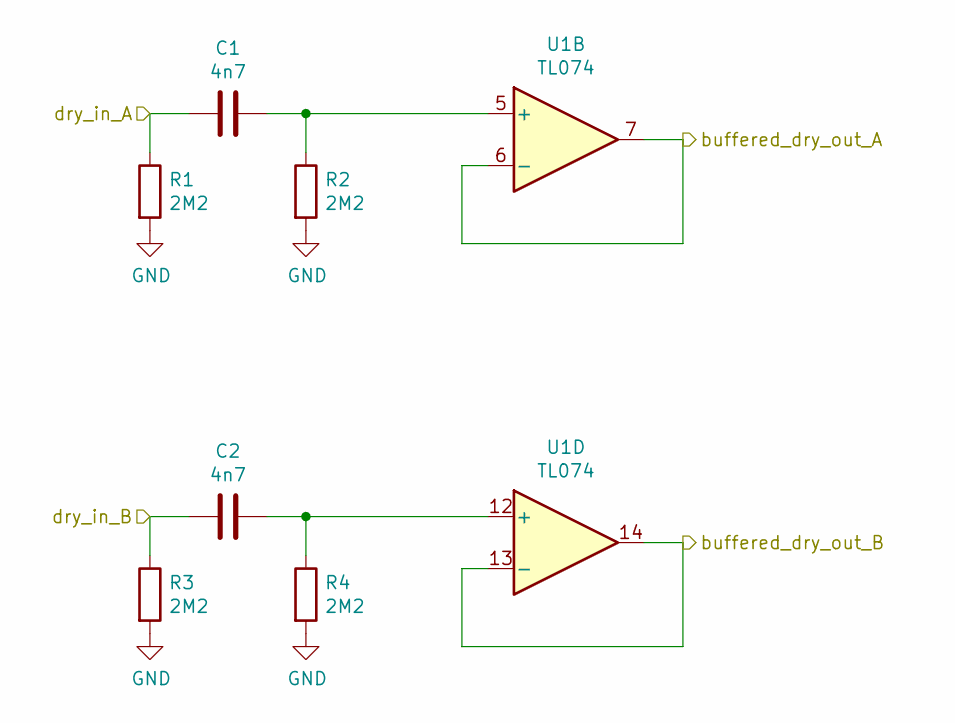
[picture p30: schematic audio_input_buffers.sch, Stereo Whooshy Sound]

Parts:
C1, C2: 4n7; C_0805_2012Metric
R1, R2, R3, R4: 2M2; R_0603_1608Metric
U1: TL074; TSSOP-14_4.4x5mm_P0.65mm

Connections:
/audio_input_buffers/dry_in_A: C1.2, R1.1; also elsewhere on the board
/audio_input_buffers/dry_in_B: C2.2, R3.1; also elsewhere on the board
/dry_A: U1.6 (-), U1.7; also elsewhere on the board
/dry_B: U1.13 (-), U1.14; also elsewhere on the board
GND: R1.2, R2.2, R3.2, R4.2; also elsewhere on the board
unnamed: C1.1, R2.1, U1.5 (+)
unnamed: C2.1, R4.1, U1.12 (+)

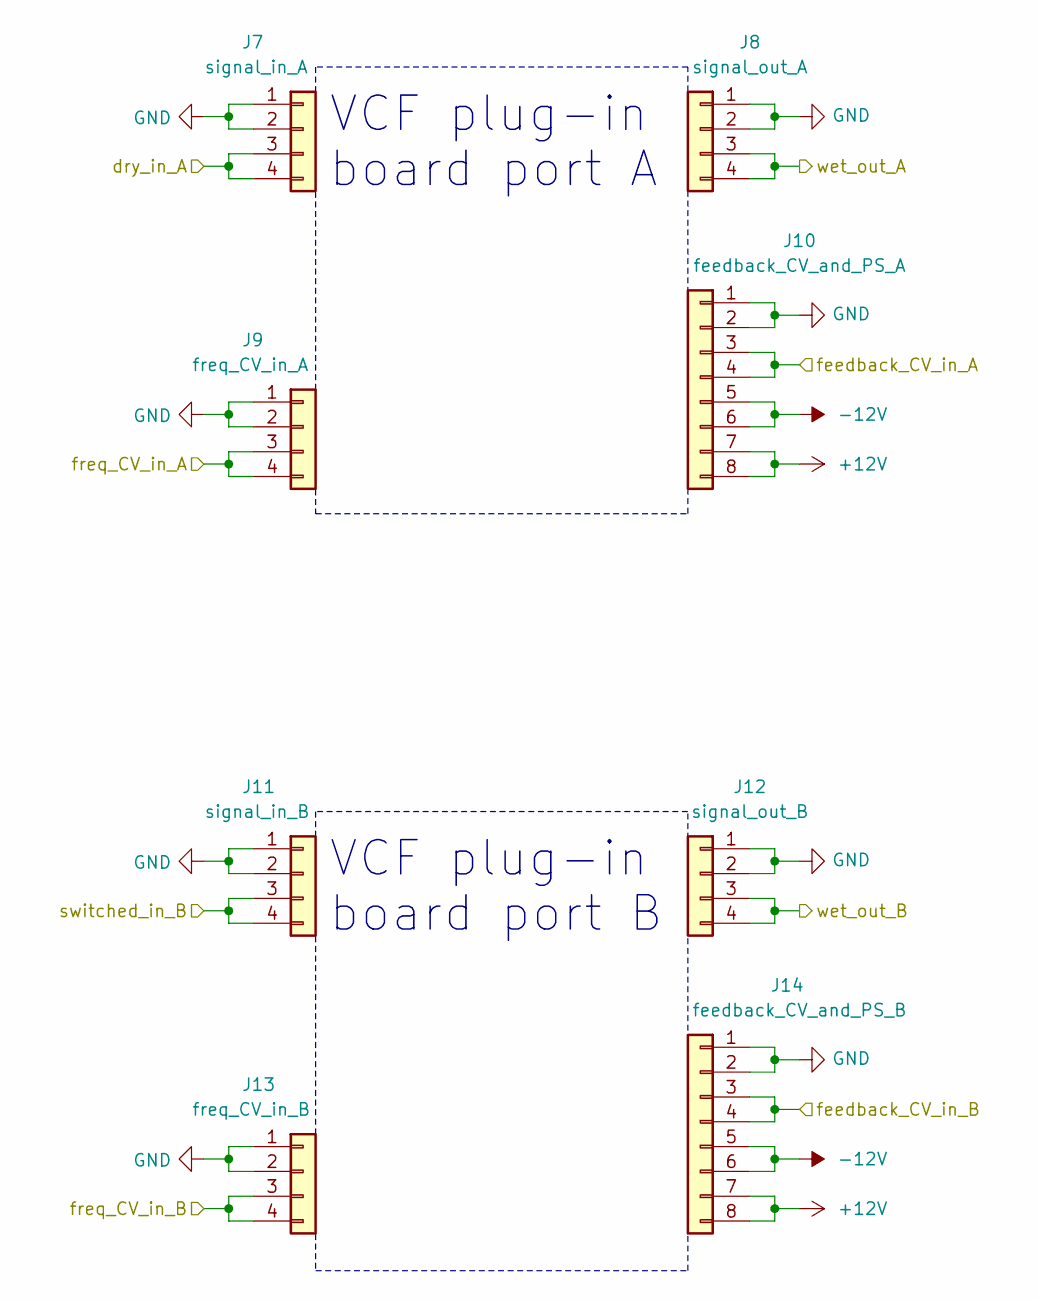
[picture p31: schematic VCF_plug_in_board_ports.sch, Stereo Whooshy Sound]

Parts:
J7: signal_in_A; PinSocket_1x04_P2.54mm_Vertical
J8: signal_out_A; PinSocket_1x04_P2.54mm_Vertical
J9: freq_CV_in_A; PinSocket_1x04_P2.54mm_Vertical
J10: feedback_CV_and_PS_A; PinSocket_1x08_P2.54mm_Vertical
J11: signal_in_B; PinSocket_1x04_P2.54mm_Vertical
J12: signal_out_B; PinSocket_1x04_P2.54mm_Vertical
J13: freq_CV_in_B; PinSocket_1x04_P2.54mm_Vertical
J14: feedback_CV_and_PS_B; PinSocket_1x08_P2.54mm_Vertical

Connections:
+12V: J10.7, J10.8, J14.7, J14.8; also elsewhere on the board
-12V: J10.5, J10.6, J14.5, J14.6; also elsewhere on the board
/VCF_plug_in_board_ports/feedback_CV_in_A: J10.3, J10.4, J14.3, J14.4; also elsewhere on the board
/VCF_plug_in_board_ports/freq_CV_in_A: J9.3, J9.4; also elsewhere on the board
/VCF_plug_in_board_ports/freq_CV_in_B: J13.3, J13.4; also elsewhere on the board
/bypass_switches/wet_in_B: J12.3, J12.4; also elsewhere on the board
/dry_A: J7.3, J7.4; also elsewhere on the board
/switched_dry_B: J11.3, J11.4; also elsewhere on the board
/wet_A: J8.3, J8.4; also elsewhere on the board
GND: J7.1, J7.2, J8.1, J8.2, J9.1, J9.2, J10.1, J10.2, J11.1, J11.2, J12.1, J12.2, J13.1, J13.2, J14.1, J14.2; also elsewhere on the board

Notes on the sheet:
VCF plug-in board port A
VCF plug-in board port B

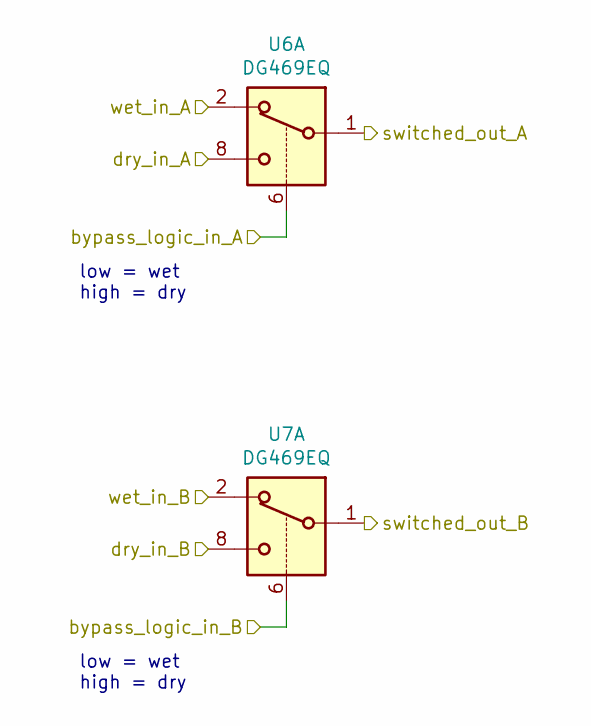
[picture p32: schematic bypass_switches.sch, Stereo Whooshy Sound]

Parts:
U6, U7: DG469EQ; MSOP-8_3x3mm_P0.65mm

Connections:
/audio_output_buffers/audio_in_A: U6.1; also elsewhere on the board
/audio_output_buffers/audio_in_B: U7.1; also elsewhere on the board
/bypass_switches/bypass_logic_in_A: U6.6; also elsewhere on the board
/bypass_switches/bypass_logic_in_B: U7.6; also elsewhere on the board
/bypass_switches/wet_in_B: U7.2; also elsewhere on the board
/dry_A: U6.8; also elsewhere on the board
/dry_B: U7.8; also elsewhere on the board
/wet_A: U6.2; also elsewhere on the board

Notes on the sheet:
low = wet high = dry

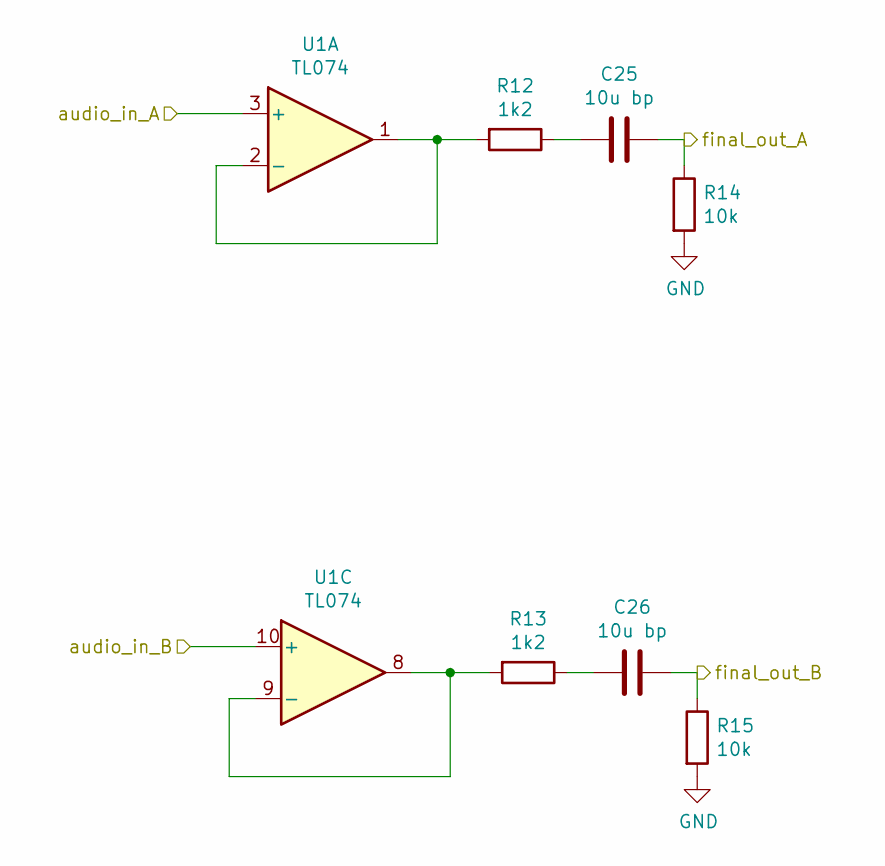
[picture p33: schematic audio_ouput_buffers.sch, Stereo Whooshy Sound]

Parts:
C25, C26: 10u bp; C_Radial_D6.3mm_H11.0mm_P2.50mm
R12, R13: 1k2; R_0603_1608Metric
R14, R15: 10k; R_0603_1608Metric
U1: TL074; TSSOP-14_4.4x5mm_P0.65mm

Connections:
/audio_output_buffers/audio_in_A: U1.3 (+); also elsewhere on the board
/audio_output_buffers/audio_in_B: U1.10 (+); also elsewhere on the board
/audio_output_buffers/final_out_A: C25.1, R14.1; also elsewhere on the board
/audio_output_buffers/final_out_B: C26.1, R15.1; also elsewhere on the board
GND: R14.2, R15.2; also elsewhere on the board
unnamed: C25.2, R12.1
unnamed: C26.2, R13.1
unnamed: R12.2, U1.1, U1.2 (-)
unnamed: R13.2, U1.8, U1.9 (-)

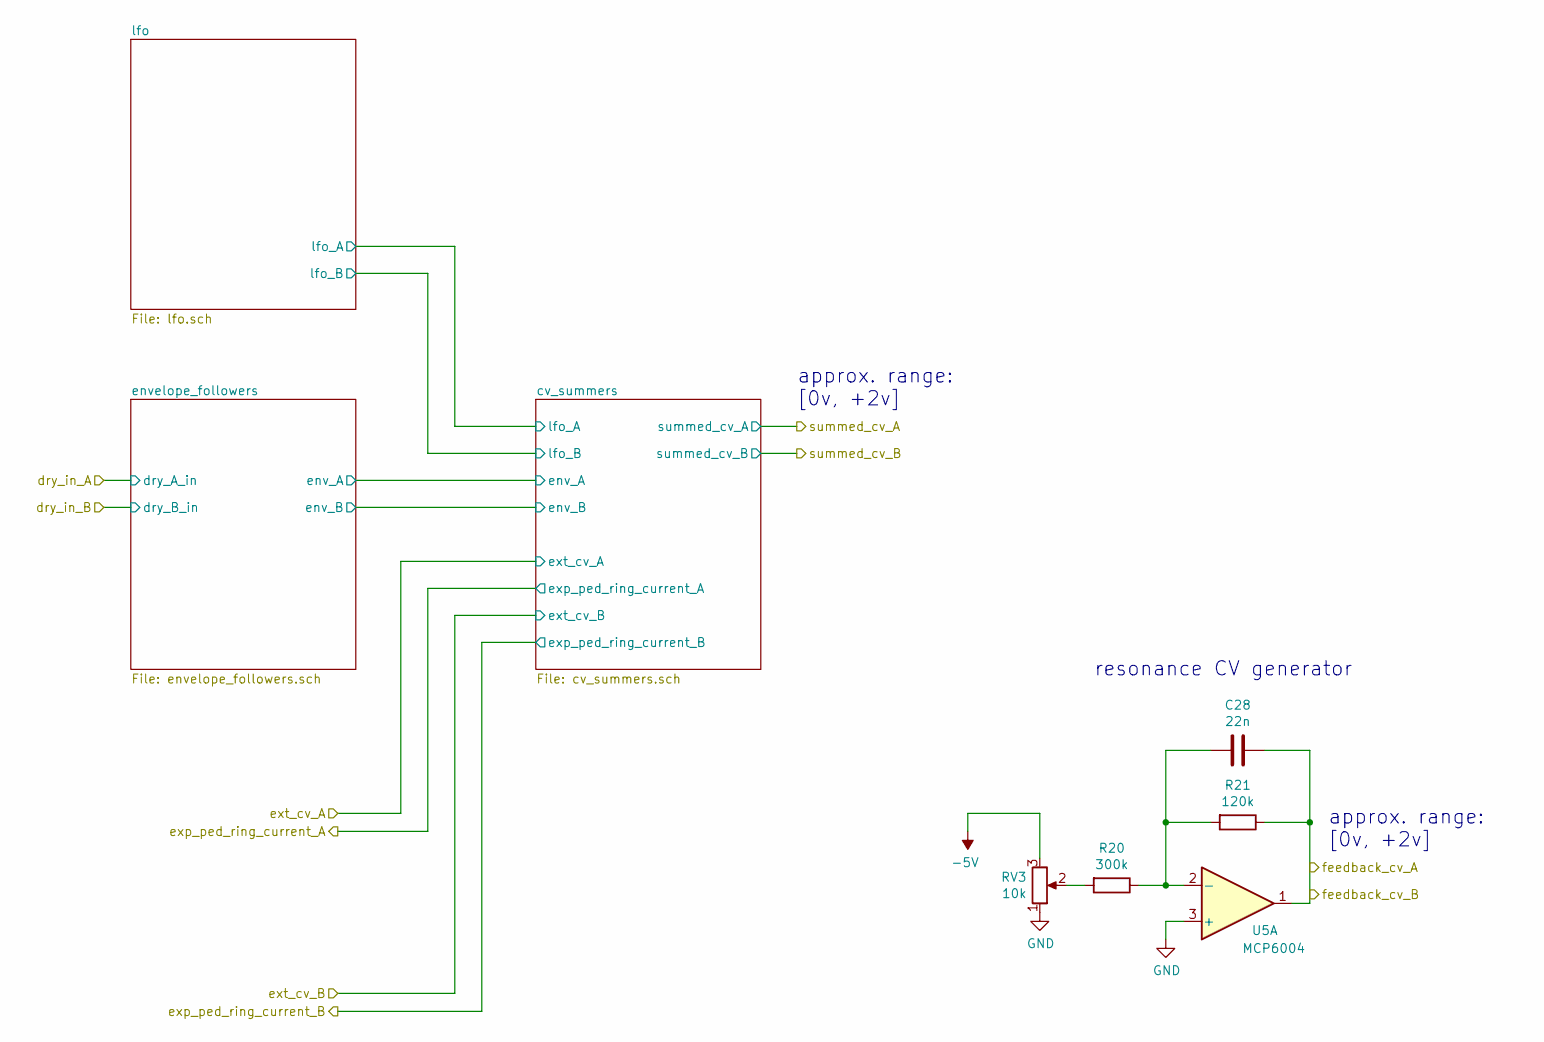
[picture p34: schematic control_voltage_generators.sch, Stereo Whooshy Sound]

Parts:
C28: 22n; C_0603_1608Metric
R20: 300k; R_0603_1608Metric
R21: 120k; R_0603_1608Metric
RV3: 10k; Potentiometer_Alpha_RD901F-40-00D_Single_Vertical
U5: MCP6004; TSSOP-14_4.4x5mm_P0.65mm

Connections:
-5V: RV3.3; also elsewhere on the board
/VCF_plug_in_board_ports/feedback_CV_in_A: C28.1, R21.1, U5.1; also elsewhere on the board
GND: RV3.1, U5.3 (+); also elsewhere on the board
unnamed: C28.2, R20.1, R21.2, U5.2 (-)
unnamed: R20.2, RV3.2

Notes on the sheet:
approx. range: [0v, +2v]
resonance CV generator

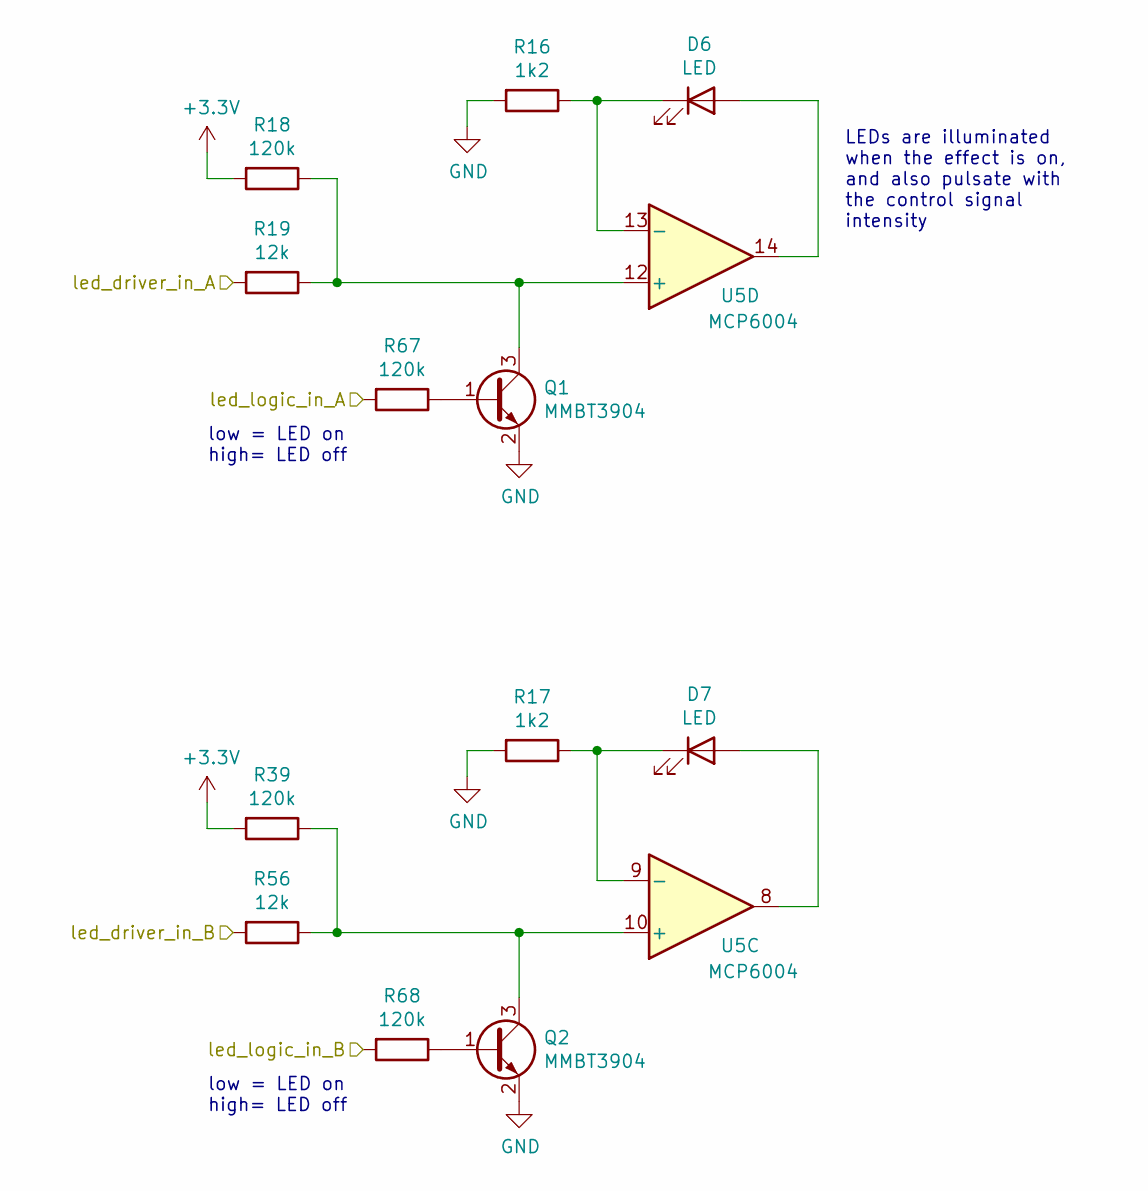
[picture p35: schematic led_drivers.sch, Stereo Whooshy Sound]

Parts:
D6, D7: LED; LED_D5.0mm
Q1, Q2: MMBT3904; SOT-23
R16, R17: 1k2; R_0603_1608Metric
R18, R39, R67, R68: 120k; R_0603_1608Metric
R19, R56: 12k; R_0603_1608Metric
U5: MCP6004; TSSOP-14_4.4x5mm_P0.65mm

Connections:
+3V3: R18.2, R39.2; also elsewhere on the board
/VCF_plug_in_board_ports/freq_CV_in_A: R19.2; also elsewhere on the board
/VCF_plug_in_board_ports/freq_CV_in_B: R56.2; also elsewhere on the board
/bypass_switches/bypass_logic_in_A: R67.2; also elsewhere on the board
/bypass_switches/bypass_logic_in_B: R68.2; also elsewhere on the board
GND: Q1.2 (E), Q2.2 (E), R16.2, R17.2; also elsewhere on the board
unnamed: D6.1 (K), R16.1, U5.13 (-)
unnamed: D6.2 (A), U5.14
unnamed: D7.1 (K), R17.1, U5.9 (-)
unnamed: D7.2 (A), U5.8
unnamed: Q1.1 (B), R67.1
unnamed: Q1.3 (C), R18.1, R19.1, U5.12 (+)
unnamed: Q2.1 (B), R68.1
unnamed: Q2.3 (C), R39.1, R56.1, U5.10 (+)

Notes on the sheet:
low = LED on high= LED off
LEDs are illuminated when the effect is on, and also pulsate with the control signal intensity

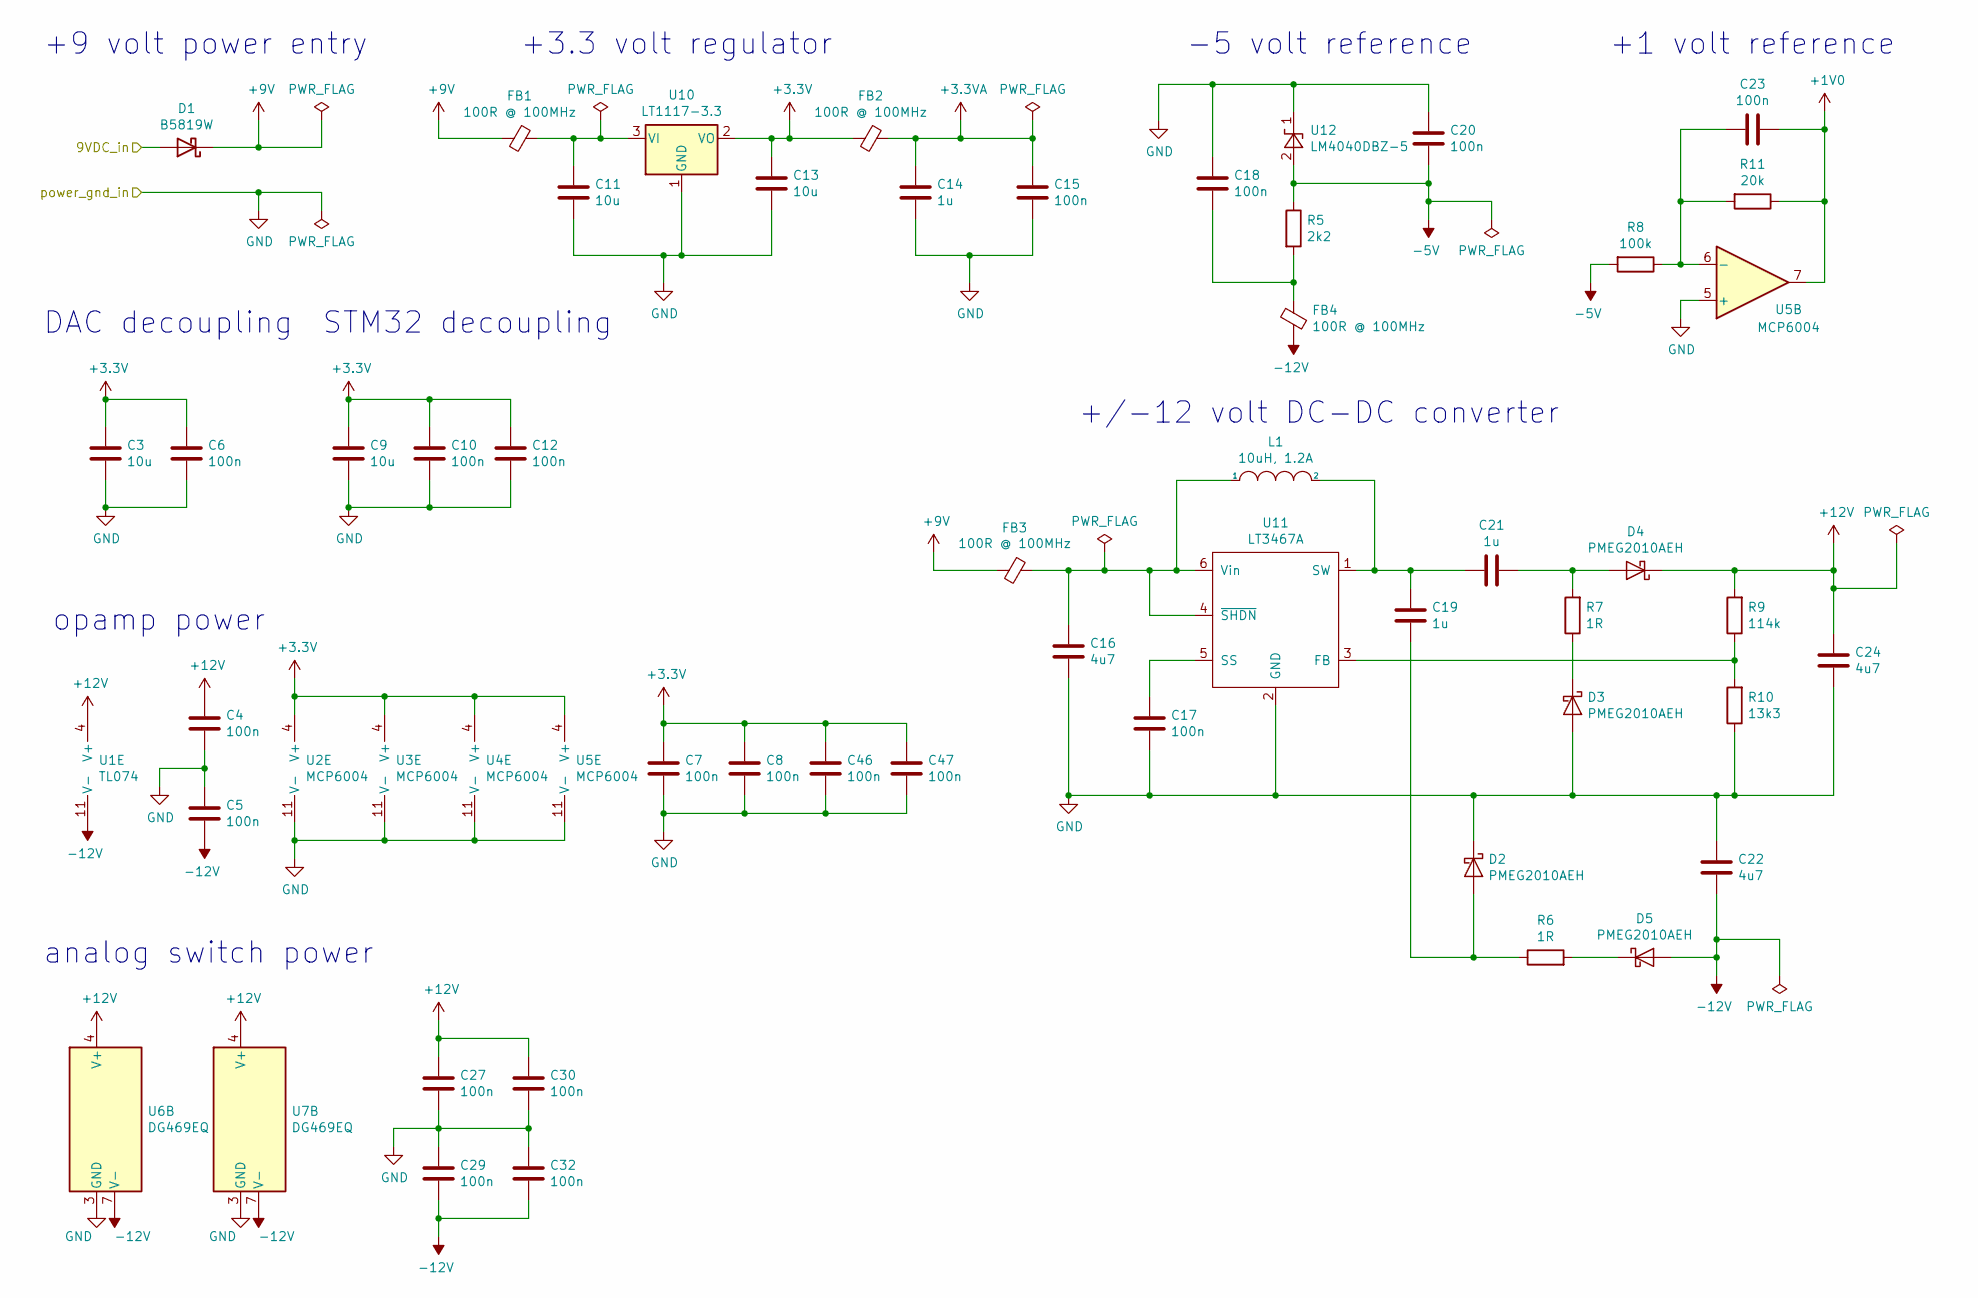
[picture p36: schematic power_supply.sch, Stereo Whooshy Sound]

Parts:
C3, C9, C11, C13: 10u; C_0805_2012Metric
C4, C5, C6, C7, C8, C10, C12, C15, C17, C18, C20, C23, C27, C29, C30, C32, C46, C47: 100n; C_0603_1608Metric
C14, C19, C21: 1u; C_0805_2012Metric
C16, C22, C24: 4u7; C_0805_2012Metric
D1: B5819W; D_SOD-123
D2, D3, D4, D5: PMEG2010AEH; D_SOD-123F
FB1, FB2, FB3, FB4: 100R @ 100MHz; L_0805_2012Metric
L1: 10uH, 1.2A; L_Taiyo-Yuden_NR-50xx
R5: 2k2; R_0603_1608Metric
R6, R7: 1R; R_0603_1608Metric
R8: 100k; R_0603_1608Metric
R9: 114k; R_0603_1608Metric
R10: 13k3; R_0603_1608Metric
R11: 20k; R_0603_1608Metric
U1: TL074; TSSOP-14_4.4x5mm_P0.65mm
U2, U3, U4, U5: MCP6004; TSSOP-14_4.4x5mm_P0.65mm
U6, U7: DG469EQ; MSOP-8_3x3mm_P0.65mm
U10: LT1117-3.3; SOT-223-3_TabPin2
U11: LT3467A; TSOT-23-6
U12: LM4040DBZ-5; SOT-23

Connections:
+1V0: C23.1, R11.1, U5.7; also elsewhere on the board
+3.3VA: C14.1, C15.1, FB2.1; also elsewhere on the board
+3V3: C3.1, C6.1, C7.1, C8.1, C9.1, C10.1, C12.1, C13.1, C46.1, C47.1, FB2.2, U2.4 (V+), U3.4 (V+), U4.4 (V+), U5.4 (V+), U10.2 (VO); also elsewhere on the board
+9V: D1.1 (K), FB1.2, FB3.2; also elsewhere on the board
+12V: C4.1, C24.1, C27.1, C30.1, D4.1 (K), R9.2, U1.4 (V+), U6.4 (V+), U7.4 (V+); also elsewhere on the board
-5V: C20.2, R5.1, R8.2, U12.2 (A); also elsewhere on the board
-12V: C5.2, C22.2, C29.2, C32.2, D5.2 (A), FB4.1, U1.11 (V-), U6.7 (V-), U7.7 (V-); also elsewhere on the board
/power_supply/9VDC_in: D1.2 (A); also elsewhere on the board
GND: C3.2, C4.2, C5.1, C6.2, C7.2, C8.2, C9.2, C10.2, C11.2, C12.2, C13.2, C14.2, C15.2, C16.2, C17.2, C18.1, C20.1, C22.1, C24.2, C27.2, C29.1, C30.2, C32.1, C46.2, C47.2, D2.1 (K), D3.2 (A), R10.1, U2.11 (V-), U3.11 (V-), U4.11 (V-), U5.5 (+), U5.11 (V-), U6.3 (GND), U7.3 (GND), U10.1 (GND), U11.2 (GND), U12.1 (K); also elsewhere on the board
unnamed: C11.1, FB1.1, U10.3 (VI)
unnamed: C16.1, FB3.1, L1.1, U11.4 (~SHDN), U11.6 (Vin)
unnamed: C17.1, U11.5 (SS)
unnamed: C18.2, FB4.2, R5.2
unnamed: C19.1, C21.2, L1.2, U11.1 (SW)
unnamed: C19.2, D2.2 (A), R6.1
unnamed: C21.1, D4.2 (A), R7.2
unnamed: C23.2, R8.1, R11.2, U5.6 (-)
unnamed: D3.1 (K), R7.1
unnamed: D5.1 (K), R6.2
unnamed: R9.1, R10.2, U11.3 (FB)

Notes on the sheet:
-5 volt reference
+/-12 volt DC-DC converter
+3.3 volt regulator
+9 volt power entry
DAC decoupling
STM32 decoupling
+1 volt reference
opamp power
analog switch power

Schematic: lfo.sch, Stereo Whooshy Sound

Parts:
C35, C36, C37, C38, C39, C40, C41: 100n; C_0603_1608Metric
C42, C43: 1u; C_0805_2012Metric
J15: swd_header; PinHeader_1x04_P2.54mm_Vertical
R42: 10k; R_0603_1608Metric
RV6, RV7, RV8, RV9, RV10, RV11: 10k; Potentiometer_Alpha_RD901F-40-00D_Single_Vertical
SW2: SW_SPDT_center_off; SPDT_mini_toggle
SW3: SW_SPDT; SPDT_mini_toggle
U8: STM32L031F4Px; TSSOP-20_4.4x6.5mm_P0.65mm
U9: MCP4822; TSSOP-8_3x3mm_P0.65mm

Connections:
+3.3VA: RV6.3, RV7.3, RV8.3, RV9.3, RV10.3, RV11.3, U8.5 (VDDA); also elsewhere on the board
+3V3: J15.1, U8.16 (VDD), U9.1 (Vdd); also elsewhere on the board
/control_voltage_generators/cv_summers/lfo_A: C43.1, U9.8 (VA); also elsewhere on the board
/control_voltage_generators/cv_summers/lfo_B: C42.1, U9.6 (VB); also elsewhere on the board
/control_voltage_generators/lfo/lfo_1_depth_cv: C37.1, RV8.2, U8.8 (PA2)
/control_voltage_generators/lfo/lfo_1_rate_cv: C35.1, RV6.2, U8.6 (PA0)
/control_voltage_generators/lfo/lfo_1_shape_cv: C36.1, RV7.2, U8.7 (PA1)
/control_voltage_generators/lfo/lfo_2_depth_cv: C40.1, RV11.2, U8.14 (PB1)
/control_voltage_generators/lfo/lfo_2_rate_cv: C38.1, RV9.2, U8.9 (PA3)
/control_voltage_generators/lfo/lfo_2_shape_cv: C39.1, RV10.2, U8.10 (PA4)
/control_voltage_generators/lfo/lfo_inv_b_sw: SW3.3 (C), U8.2 (PC14)
/control_voltage_generators/lfo/lfo_mode_sw_1: SW2.1 (A), U8.17 (PA9)
/control_voltage_generators/lfo/lfo_mode_sw_2: SW2.3 (C), U8.18 (PA10)
/control_voltage_generators/lfo/spi1_dac_cs: U8.12 (PA6), U9.2 (~CS)
/control_voltage_generators/lfo/spi1_mosi: U8.13 (PA7), U9.4 (SDI)
/control_voltage_generators/lfo/spi1_sck: U8.11 (PA5), U9.3 (SCK)
/control_voltage_generators/lfo/sys_swclk: J15.2, U8.20 (PA14)
/control_voltage_generators/lfo/sys_swdio: J15.4, U8.19 (PA13)
GND: C35.2, C36.2, C37.2, C38.2, C39.2, C40.2, C41.2, C42.2, C43.2, J15.3, R42.2, RV6.1, RV7.1, RV8.1, RV9.1, RV10.1, RV11.1, SW2.2 (B), SW3.2 (B), U8.15 (VSS), U9.5 (~LDAC), U9.7 (Vss); also elsewhere on the board
unnamed: C41.1, U8.4 (NRST)
unnamed: R42.1, U8.1 (BOOT0)

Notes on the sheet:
approx. range: [0v, +2v]

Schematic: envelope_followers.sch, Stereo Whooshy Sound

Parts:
C44, C45: 470n; C_0805_2012Metric
R43, R57: 20k; R_0603_1608Metric
R44, R58: 10k; R_0603_1608Metric
R45, R59: 30k; R_0603_1608Metric
R46, R60: 4k7; R_0603_1608Metric
R47, R61: 1k2; R_0603_1608Metric
R48, R49, R50, R62, R63, R64: 100k; R_0603_1608Metric
RV4: 500k_dual; Potentiometer_Alpha_RD902F-40-00D_Dual_Vertical
RV5: 10k_dual; Potentiometer_Alpha_RD902F-40-00D_Dual_Vertical
RV14, RV15: 100k trim; bourns_3306F
SW4: SW_DPDT_center_off; DPDT_mini_toggle
U2, U3: MCP6004; TSSOP-14_4.4x5mm_P0.65mm

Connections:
+1V0: RV5.1, RV5.4, SW4.1 (A), SW4.3 (C), SW4.4 (A); also elsewhere on the board
/control_voltage_generators/cv_summers/env_A: RV5.2; also elsewhere on the board
/control_voltage_generators/cv_summers/env_B: RV5.5; also elsewhere on the board
/dry_A: R43.2; also elsewhere on the board
/switched_dry_B: R57.2; also elsewhere on the board
GND: C44.2, C45.2, R47.1, R61.1, U2.3 (+), U3.3 (+); also elsewhere on the board
unnamed: C44.1, RV4.2, RV4.3, U2.10 (+)
unnamed: C45.1, RV4.5, RV4.6, U3.10 (+)
unnamed: R43.1, R44.2, U2.2 (-)
unnamed: R44.1, R45.1, U2.5 (+)
unnamed: R45.2, U2.1
unnamed: R46.1, RV4.1
unnamed: R46.2, RV14.1, U2.7
unnamed: R47.2, RV14.2, RV14.3, U2.6 (-)
unnamed: R48.1, R50.2, U2.13 (-)
unnamed: R48.2, R49.2, U2.8, U2.9 (-)
unnamed: R49.1, SW4.2 (B), U2.12 (+)
unnamed: R50.1, RV5.3, U2.14
unnamed: R57.1, R58.2, U3.2 (-)
unnamed: R58.1, R59.1, U3.5 (+)
unnamed: R59.2, U3.1
unnamed: R60.1, RV4.4
unnamed: R60.2, RV15.1, U3.7
unnamed: R61.2, RV15.2, RV15.3, U3.6 (-)
unnamed: R62.1, R64.2, U3.13 (-)
unnamed: R62.2, R63.2, U3.8, U3.9 (-)
unnamed: R63.1, SW4.5 (B), U3.12 (+)
unnamed: R64.1, RV5.6, U3.14

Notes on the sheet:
Attack
envelope A trim
trim for approx. range: [0v, +2v]
envelope level
approx. range: [0v, +2v]
envelope mode switch: up-up down-down up-down
envelope B trim

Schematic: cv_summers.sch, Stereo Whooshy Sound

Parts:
C31: 100n; C_0603_1608Metric
C33, C34: 22n; C_0603_1608Metric
R22, R23, R28: 10k; R_0603_1608Metric
R24, R34: 100k; R_0603_1608Metric
R25, R29, R33, R35, R36, R55, R65, R66: 300k; R_0603_1608Metric
R26, R30, R31, R32, R37, R38, R40, R41: 120k; R_0603_1608Metric
R27: 12k; R_0603_1608Metric
RV1, RV2: 10k; Potentiometer_Alpha_RD901F-40-00D_Single_Vertical
RV12, RV13: 100k trim; bourns_3306F
U4: MCP6004; TSSOP-14_4.4x5mm_P0.65mm

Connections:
+9V: RV12.1, RV12.2, RV13.1, RV13.2; also elsewhere on the board
-5V: R33.2, R66.2, RV1.3, RV2.3; also elsewhere on the board
/VCF_plug_in_board_ports/freq_CV_in_A: C33.1, R40.1, U4.1; also elsewhere on the board
/VCF_plug_in_board_ports/freq_CV_in_B: C34.1, R41.1, U4.14; also elsewhere on the board
/control_voltage_generators/cv_summers/env_A: R32.2; also elsewhere on the board
/control_voltage_generators/cv_summers/env_B: R38.2; also elsewhere on the board
/control_voltage_generators/cv_summers/lfo_A: R31.2; also elsewhere on the board
/control_voltage_generators/cv_summers/lfo_B: R37.2; also elsewhere on the board
/control_voltage_generators/cv_summers/manual_freq: R29.2, R35.2, RV1.2
/control_voltage_generators/cv_summers/separation_A: C31.1, R26.1, R30.2, U4.7
/control_voltage_generators/cv_summers/separation_B: R25.2, R36.2, RV2.2
/control_voltage_generators/exp_ped_ring_current_A: R22.2; also elsewhere on the board
/control_voltage_generators/exp_ped_ring_current_B: R23.2; also elsewhere on the board
/control_voltage_generators/ext_cv_A: R34.2; also elsewhere on the board
/control_voltage_generators/ext_cv_B: R24.2; also elsewhere on the board
GND: R27.2, R28.2, RV1.1, RV2.1, U4.5 (+), U4.10 (+); also elsewhere on the board
unnamed: C31.2, R26.2, R55.1, U4.6 (-)
unnamed: C33.2, R29.1, R30.1, R31.1, R32.1, R33.1, R40.2, U4.2 (-)
unnamed: C34.2, R35.1, R37.1, R38.1, R41.2, R65.1, R66.1, U4.13 (-)
unnamed: R22.1, RV12.3
unnamed: R23.1, RV13.3
unnamed: R24.1, R27.1, U4.12 (+)
unnamed: R25.1, R55.2
unnamed: R28.1, R34.1, U4.3 (+)
unnamed: R36.1, R65.2
unnamed: U4.8, U4.9 (-)

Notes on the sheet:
range: [0v, +2v]
range: [-5v, 0v]
approx. useful range: [0v, +2v]
range: [0v, +5v]
adjust such that +5v is developed across an expression pedal connected via the Tip-Ring-Sleeve jack.

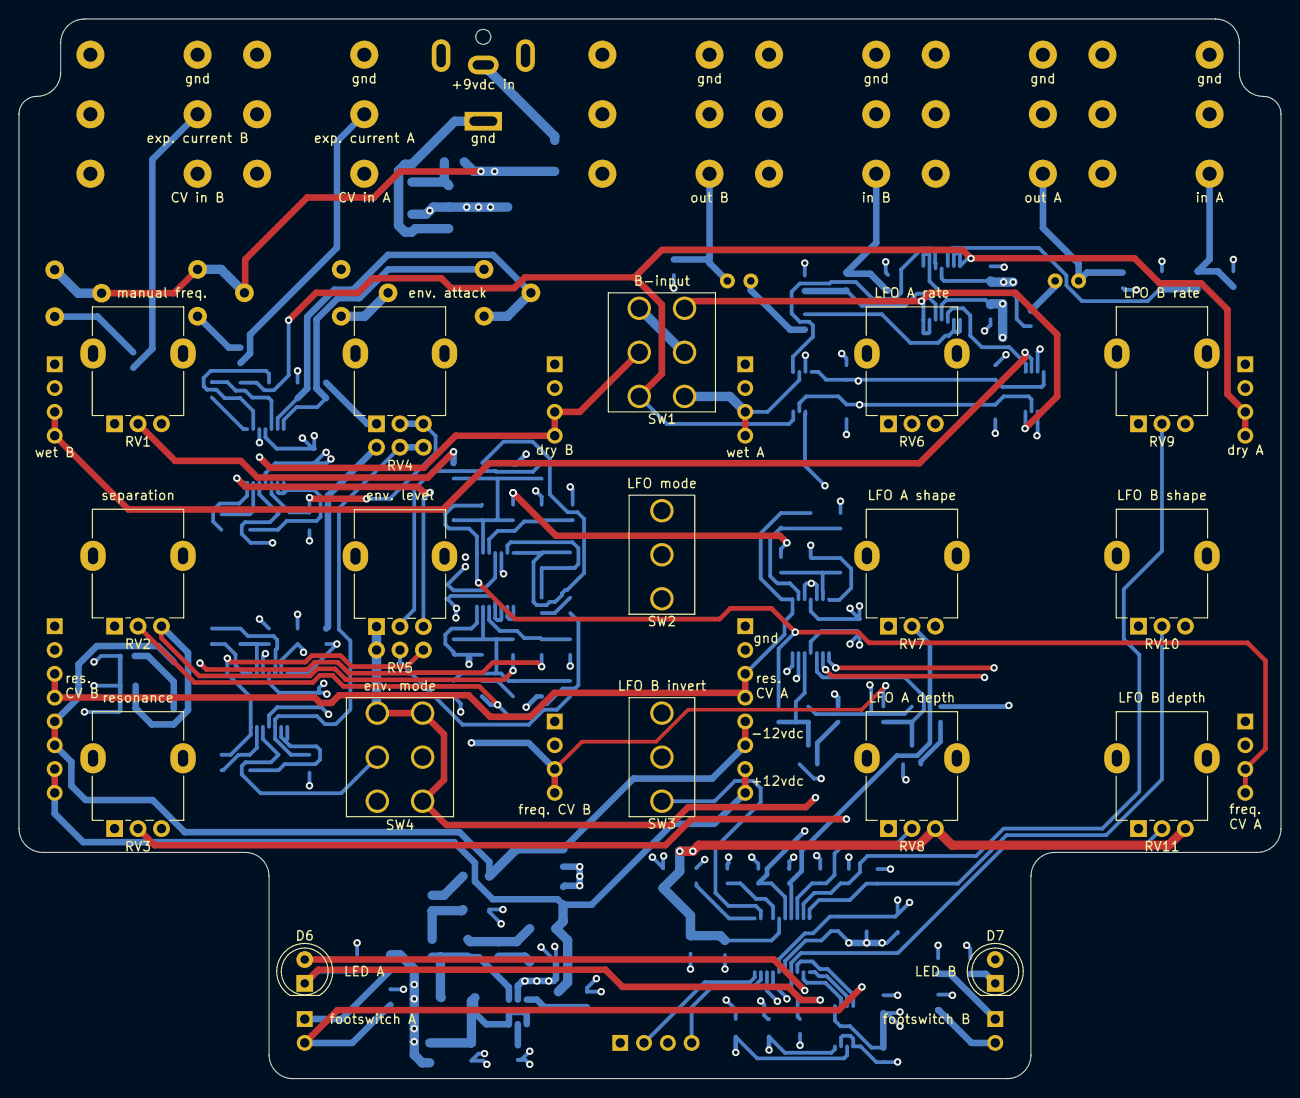
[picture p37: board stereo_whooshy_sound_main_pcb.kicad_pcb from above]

Board: 4 copper layers, 134.6 x 113.0 mm, 178 parts (0 on the bottom side), 114 nets.

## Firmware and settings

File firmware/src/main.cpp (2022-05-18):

#include "BSP_system_init.hpp"
#include "BSP_TIM2.hpp"
#include "LFO.hpp"
#include "lookup_tables.hpp"
#include "MCP4822.hpp"
#include "ui_controls.hpp"

/* the two independent LFO objects */
LFO lfo_A(BSP::tim2::FREQUENCY_Hz);
LFO lfo_B(BSP::tim2::FREQUENCY_Hz);

/* the user interface components, pots and switches */
UI ui{};

/**
 * @brief read the LFO rate controls and update the frequency for LFO A and B
 */
void update_lfo_frequency();

/**
 * @brief read the LFO wave shape controls and update the waveshapes for LFO A and B
 */
void update_lfo_wave_scanners();

/**
 * @brief calculate the final value to write to the DAC for output A
 *
 * When the sweep mode is INDEPENDENT or SYNC_TO_A, this is the value of LFO A
 * scaled by the depth A control
 *
 * When the sweep mode is ADD, this is the value of value of LFO A
 * scaled by the depth A control plus the value of LFO B scaled by
 * the depth B control
 *
 * @return int the value to write to the DAC for output A
 */
int calc_lfo_A_val();

/**
 * @brief calculate the final value to write to the DAC for output B
 *
 * When the sweep mode is INDEPENDENT, this is the value of LFO B
 * scaled by the depth B control, or -(LFO B) if the invert B switch is on
 *
 * When the sweep mode is SYNC_TO_A, this is the value of LFO A scaled by the
 * depth B control, or -(LFO A) if the invert B switch is on
 *
 * When the sweep mode is ADD, this is the value of LFO A
 * scaled by the depth A control plus the value of LFO B scaled by
 * the depth B control, or (LFO A) - (LFO B) if the invert B switch is on
 *
 * @return int
 */
int calc_lfo_B_val();

/**
 * @brief write the values of LFO A and B to the SPI DAC
 */
void write_to_dacs();

int main(void)
{
    BSP::system_init::init();

    while (1)
    {
        if (BSP::tim2::getTimeout())
        {
            lfo_A.tick();
            lfo_B.tick();

            update_lfo_frequency();
            update_lfo_wave_scanners();
            write_to_dacs();
        }
    }

    // never reached
    return 0;
}

void update_lfo_frequency()
{
    auto freq_lut_idx_ui10 = ui.get_control_signal_val(UI::LFO_A_FREQ);
    lfo_A.setInput(LFO::FREQ_mHz, Lookup_Tables::EXPO_MAPPING_LUT_mHz[freq_lut_idx_ui10]);

    freq_lut_idx_ui10 = ui.get_control_signal_val(UI::LFO_B_FREQ);
    lfo_B.setInput(LFO::FREQ_mHz, Lookup_Tables::EXPO_MAPPING_LUT_mHz[freq_lut_idx_ui10]);
}

void update_lfo_wave_scanners()
{
    lfo_A.setInput(
        LFO::WAVE_SCAN,
        ui.get_control_signal_val(UI::LFO_A_SHAPE));

    lfo_B.setInput(
        LFO::WAVE_SCAN,
        ui.get_control_signal_val(UI::LFO_B_SHAPE));
}

int calc_lfo_A_val()
{
    int retval;

    switch (ui.get_sweep_mode())
    {
    // in INDEPENDENT and SYNC_TO_A modes just take the val of LFO A
    case UI::sweep_mode::INDEPENDENT:
    case UI::sweep_mode::SYNC_TO_A:
    {
        retval = ui.scale_bipolar_signal(
            lfo_A.getOutput(LFO::CROSSFADED),
            ui.get_control_signal_val(UI::LFO_A_LEVEL));
        break;
    }
    // in ADD mode, take (LFO A) + (LFO B)
    case UI::sweep_mode::ADD:
    {
        auto lfo_A_contrib = ui.scale_bipolar_signal(
            lfo_A.getOutput(LFO::CROSSFADED),
            ui.get_control_signal_val(UI::LFO_A_LEVEL));

        auto lfo_B_contrib = ui.scale_bipolar_signal(
            lfo_B.getOutput(LFO::CROSSFADED),
            ui.get_control_signal_val(UI::LFO_B_LEVEL));

        retval = lfo_A_contrib + lfo_B_contrib;
        break;
    }
    }

    return ui.condition_bipolar_signal_for_DAC(retval);
}

int calc_lfo_B_val()
{
    const auto lfo_B_mode = ui.get_lfo_b_mode();

    int retval;

    switch (ui.get_sweep_mode())
    {
    // in INDEPENDENT mode just take the val of LFO B, optionally inverted
    case UI::sweep_mode::INDEPENDENT:
    {
        retval = ui.scale_bipolar_signal(
            lfo_B.getOutput(LFO::CROSSFADED),
            ui.get_control_signal_val(UI::LFO_B_LEVEL));

        if (lfo_B_mode == UI::lfo_b_mode::INVERT)
        {
            retval = -retval;
        }
        break;
    }
    // in SYNC_TO_A modes just take the val of LFO A, optionally inverted
    case UI::sweep_mode::SYNC_TO_A:
    {
        retval = ui.scale_bipolar_signal(
            lfo_A.getOutput(LFO::CROSSFADED),
            ui.get_control_signal_val(UI::LFO_B_LEVEL));

        if (lfo_B_mode == UI::lfo_b_mode::INVERT)
        {
            retval = -retval;
        }
        break;
    }
    // in ADD mode, take (LFO A) + (LFO B), with LFO B optionally inverted
    case UI::sweep_mode::ADD:
    {
        auto lfo_A_contrib = ui.scale_bipolar_signal(
            lfo_A.getOutput(LFO::CROSSFADED),
            ui.get_control_signal_val(UI::LFO_A_LEVEL));

        auto lfo_B_contrib = ui.scale_bipolar_signal(
            lfo_B.getOutput(LFO::CROSSFADED),
            ui.get_control_signal_val(UI::LFO_B_LEVEL));

        if (ui.get_lfo_b_mode() == UI::lfo_b_mode::INVERT)
        {
            lfo_B_contrib = -lfo_B_contrib;
        }

        retval = lfo_A_contrib + lfo_B_contrib;
        break;
    }
    }

    return ui.condition_bipolar_signal_for_DAC(retval);
}

void write_to_dacs()
{
    MCP4822::write(calc_lfo_A_val(), MCP4822::Channel::A);
    MCP4822::write(calc_lfo_B_val(), MCP4822::Channel::B);
}

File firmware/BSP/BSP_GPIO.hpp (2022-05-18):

#pragma once

/** @brief General Purpose Input Output pins */
namespace BSP::gpio
{
    /**
     * @brief Initialize the GPIO pins.
     *
     * PA0 is an analog input mapped to the rate A CV input.
     * PA1 is an analog input mapped to the shape A CV input.
     * PA2 is an analog input mapped to the level A CV input.
     *
     * PA3 is an analog input mapped to the rate B CV input.
     * PA4 is an analog input mapped to the shape B CV input.
     *
     * PA5 is SPI1 SCK.
     * PA6 is SPI1 NSS DAC chip select.
     * PA7 is SPI1 MOSI
     *
     * PA9 is an input pullup mapped to the mode switch 1
     * PA10 is an input pullup mapped to the mode switch 2
     *
     * PA13 is SYS SWDIO
     * PA14 is SYS SWCLK
     *
     * PB1 is an analog input mapped to the level B CV input.
     *
     * PC14 is an input pullup mapped to the invert B switch
     */
    void init(void);

    /** @brief enumeration of the digital input pins. */
    enum class pin_t
    {
        PA9,
        PA10,
        PC14
    };

    /**
     * @brief Get the state of the given pin.
     *
     * @param pin the input pin to get
     * @return bool 1 if the pin is high, else 0
     */
    bool getPinState(pin_t pin);
}

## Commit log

2021-01-27 progress on schemo
    [analog_mux.sch, audio_input_buffers.sch, audio_ouput_buffers.sch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]
2021-08-07 progress on pcb layout
    [VCF_plug_in_board_ports.sch, analog_mux.sch, audio_input_buffers.sch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]
2021-08-08 reduce analog switch count, tidy up
    [bypass_switches.sch, led_drivers.sch, lfo.sch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]
2021-08-08 tidy up kicad docs
    [cv_summers.sch, envelope_followers.sch, power_supply.sch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]
2021-08-08 generate interactive BOM
2021-08-08 generate jlcpcb assembly docs
    [stereo_whooshy_sound_BOM.csv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]
2021-08-08 tidy up
    [cv_summers.sch, stereo_whooshy_sound_main_pcb.kicad_pcb]
2021-08-08 generate gerbers
    [stereo_whooshy_sound_main_pcb-B_Mask.gbs, stereo_whooshy_sound_main_pcb-B_Paste.gbp, stereo_whooshy_sound_main_pcb-B_SilkS.gbo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]
2021-08-08 remove warnings from schematic pdf
2021-12-25 add front panel
    [stereo_whooshy_sound_front_panel-B_Mask.gbs, stereo_whooshy_sound_front_panel-B_Paste.gbp, stereo_whooshy_sound_front_panel-B_SilkS.gbo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]
2022-05-17 Fix prob with MODER constant, enable port B and C
    [BSP_GPIO.cpp]
2022-05-18 Minor ADC name changes
2022-05-18 Change GPIO initialization, add get GPIO pin function
2022-05-18 Add debounced switch module
2022-05-18 Fix import bug in UI controls
    [ui_controls.cpp]
2022-07-31 Update front panel, now KiCad 6, tweak graphics
    [stereo_whooshy_sound_front_panel-3D.step, stereo_whooshy_sound_front_panel-B_Cu.dxf, stereo_whooshy_sound_front_panel-B_Mask.dxf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]
2022-07-31 Add jack panel documents
    [stereo_whooshy_sound_jack_panel-B_Cu.dxf, stereo_whooshy_sound_jack_panel-B_Mask.dxf, stereo_whooshy_sound_jack_panel-B_Silkscreen.dxf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]

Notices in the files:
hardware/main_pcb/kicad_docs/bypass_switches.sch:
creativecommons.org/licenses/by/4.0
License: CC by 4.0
